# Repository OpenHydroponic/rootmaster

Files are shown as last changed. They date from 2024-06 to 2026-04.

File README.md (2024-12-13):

# RootMaster

RootMaster is an open-source hydroponics system designed to help you grow plants efficiently using a soilless solution. This project aims to provide an affordable and customizable solution for home gardeners and small-scale farmers.

## Features

- Automated nutrient delivery system
- pH and EC monitoring
- Temperature and humidity control
- Remote monitoring and control via a web interface
- Modular design for easy expansion

## Documentation

https://openhydroponics.com/hw/rootmaster

## License

This project is licensed under the CERN Open Hardware License. See the [LICENSE](LICENSE) file for details.

## Contact

For questions or support, please open an issue on the [GitLab repository](https://gitlab.com/openhydroponics/hw/rootmaster/-/issues).

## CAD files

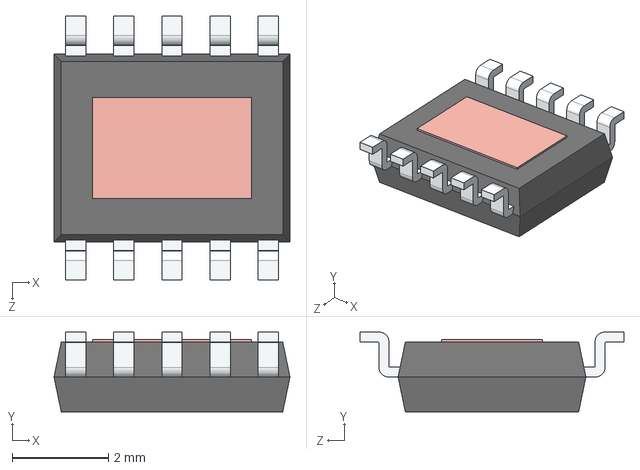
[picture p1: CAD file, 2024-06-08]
3d/ESOP-10.STEP
4.90 x 1.66 x 5.48 mm

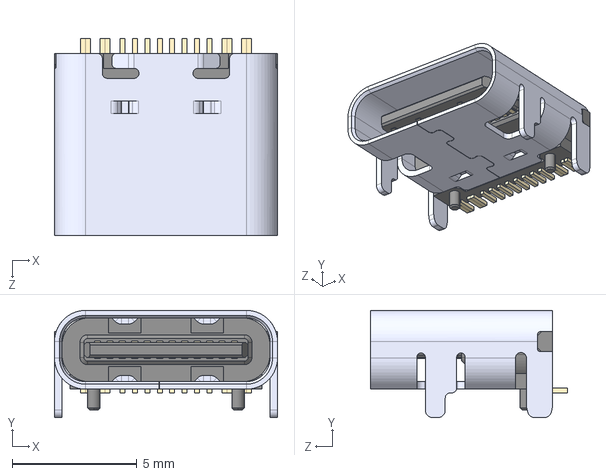
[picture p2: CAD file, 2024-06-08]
3d/TYPE-C-31-M-12--3DModel-STEP-56544.STEP
8.94 x 4.30 x 7.90 mm

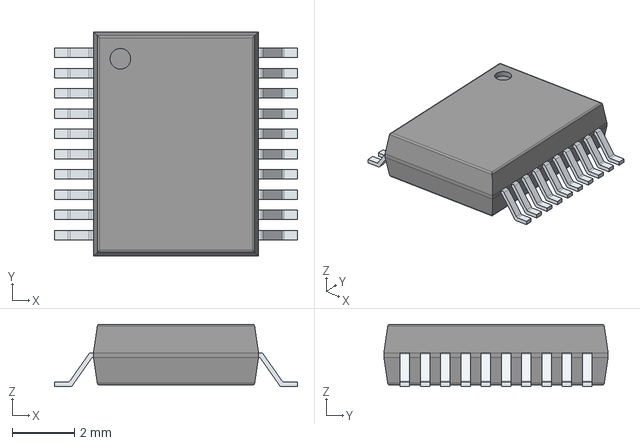
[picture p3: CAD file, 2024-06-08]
3d/ADUM6010ARSZ.stp
7.80 x 7.20 x 2.00 mm
PinsArrayLR

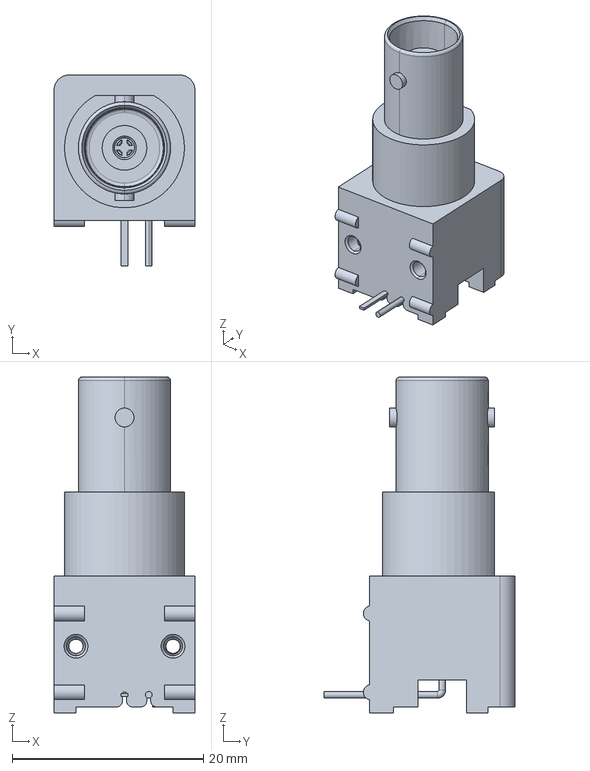
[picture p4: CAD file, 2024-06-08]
3d/c-5226990-6-b-3d.stp
14.8 x 20.0 x 35.2 mm

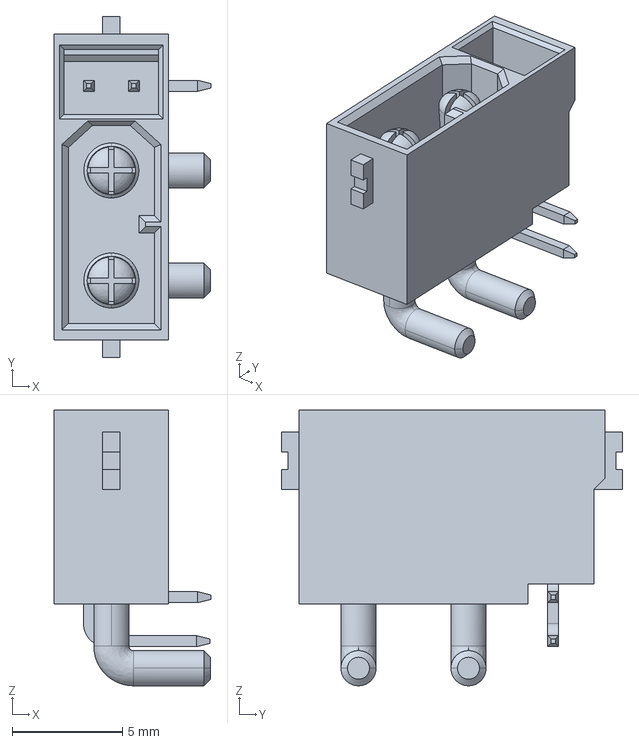
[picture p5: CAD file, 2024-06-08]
3d/XT30(2+2)PW-M 3D DRAWING.STEP.STEP
7.12 x 15.5 x 12.5 mm

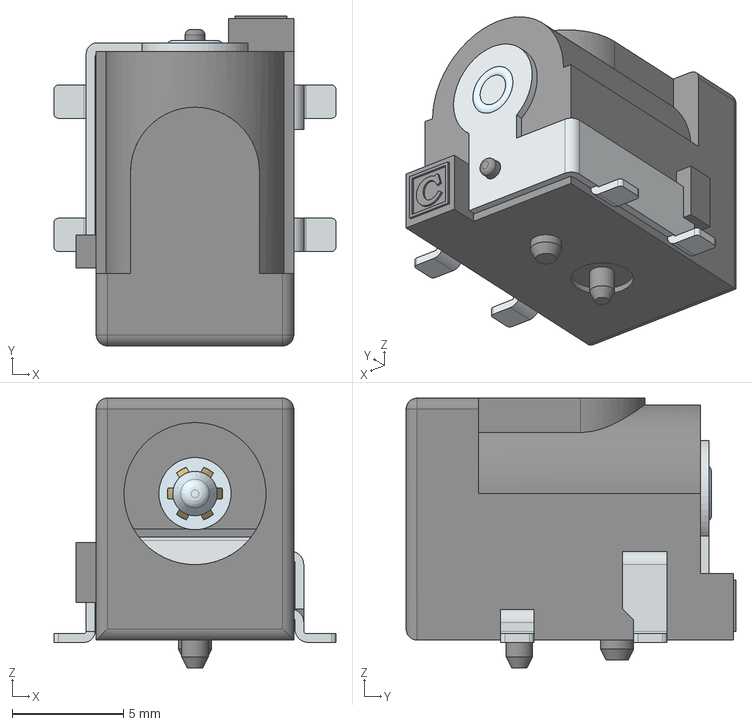
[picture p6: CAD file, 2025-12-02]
3d/FC681465S-smd.stp
12.7 x 14.8 x 12.2 mm

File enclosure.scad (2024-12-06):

include <./YAPP_Box/YAPPgenerator_v3.scad>

myPcb = "./RootMaster.stl";

//-- pcb dimensions
pcbLength           = 101; // Front to back
pcbWidth            = 101; // Side to side
pcbThickness        = 1.6;

//-- padding between pcb and inside wall
paddingFront        = 0.15;
paddingBack         = 0.15;
paddingRight        = 0.15;
paddingLeft         = 0.15;

// Base
basePlaneThickness  = 4.0;
baseWallHeight      = 10;

// Lid
lidWallHeight       = 16;
lidPlaneThickness   = 1.2;

//-- Thickness
wallThickness       = 2;


//-- ridge where base and lid off box can overlap
//-- Make sure this isn't less than lidWallHeight
ridgeHeight         = 4;
ridgeSlack          = 0.2;

//-- the radius of all outside edges and corners
roundRadius         = 2.0;

//-- How much the PCB needs to be raised from the base
//-- to leave room for solderings and whatnot
standoffHeight      = 4.0;  //-- used for PCB Supports, Push Button and showPCB
standoffDiameter    = 6;
standoffPinDiameter = 2.8;
standoffHoleSlack   = 0.3;

snapJoins =
[
    [15, 5, yappLeft, yappSymmetric, yappCenter],
    [58, 5, yappRight, yappCenter]
];

pcbStands =
[
    [4, 4, , yappDefault, yappDefault, yappDefault, yappDefault, yappDefault, 2, yappBaseOnly, yappPin, yappAllCorners],
];

cutoutsBack =
[
    [9.4, 02, 8.4, 6, 0, yappRectangle],
    [19.6, 02, 10.9, 6, 0, yappRectangle],
    [36.75, 02, 8.4, 6, 0, yappRectangle],
    [47.26, 02, 8.4, 6, 0, yappRectangle],
    [64.6, 2, 15.7, 13, 7, yappCircle], // pH
];
ridgeExtBack =
[
    [63, 17, basePlaneThickness+2+3]
];

cutoutsLeft =
[
    [56.9, 1.5, 9.2, 3.6, 0, yappRectangle], // Usb
    [43.3, 1.5, 9.4, 11.2, 0, yappRectangle], // Barreljack
];
ridgeExtLeft =
[
    [56, 11.2, 2.5]
];

cutoutsFront =
[
    [11, 1.5, 9.5, 8.3, 0, yappRectangle],   // Pump 1
    [24.7, 1.5, 9.5, 8.3, 0, yappRectangle], // Pump 2
    [38, 1.5, 9.5, 8.3, 0, yappRectangle],   // Pump 3
    [50.4, 1.5, 10.9, 6, 0, yappRectangle],// Valve 3
    [63, 1.5, 8.4, 6, 0, yappRectangle],   // Valve 2
    [73.3, 1.5, 8.4, 6, 0, yappRectangle], // Valve 1
];

cutoutsRight =
[
    [8.3, 1.5, 8.3, 5.4, 0, yappRectangle], // DigIn 1
    [16.6+1.45, 1.5, 8.3, 5.4, 0, yappRectangle],   // DigIn 2
    [26.35+1.45, 1.5, 8.3, 5.4, 0, yappRectangle],// DigIn 3
    [77.4, 1, 16.1, 6, 0, yappRectangle],   // XT30(2+2)
];

labelsPlane =
[
    [ 30, 6, 0, 0.2, yappBack, "Liberation Mono:style=bold", 3, "PH" ],
    [ 47.3, 6, 0, 0.2, yappBack, "Liberation Mono:style=bold", 3, "TEMP" ],
    [ 60, 6, 0, 0.2, yappBack, "Liberation Mono:style=bold", 3, "EC" ],
    [ 73.2, 6, 0, 0.2, yappBack, "Liberation Mono:style=bold", 3, "FLOW" ],
     [ 85, 6, 0, 0.2, yappBack, "Liberation Mono:style=bold", 3, "TEMP" ],
];

function mountLength() = pcbLength + wallThickness*2;
boxMounts =
[
    [10, 3.5, 0, 3, yappBack, yappBase],
    [mountLength()-10, 3.5, 0, 3, yappBack, yappBase],
    [10, 3.5, 0, 3, yappFront, yappBase],
    [mountLength()-10, 3.5, 0, 3, yappFront, yappBase],
];

//-- which part(s) do you want to print?
printBaseShell        = true;
printLidShell         = true;
printSwitchExtenders  = false;


// debug
//inspectX = 6;
//inspectY = 75;
showSideBySide = true;
hideBaseWalls = false;
hideLidWalls = false;
showPcb = true;

YAPPgenerate();


if (showPcb)
{
  translate([
    wallThickness+paddingBack,
    wallThickness+paddingLeft,
    basePlaneThickness+standoffHeight
  ])
  {
    rotate([0,0,0]) import(myPcb);
  }
}

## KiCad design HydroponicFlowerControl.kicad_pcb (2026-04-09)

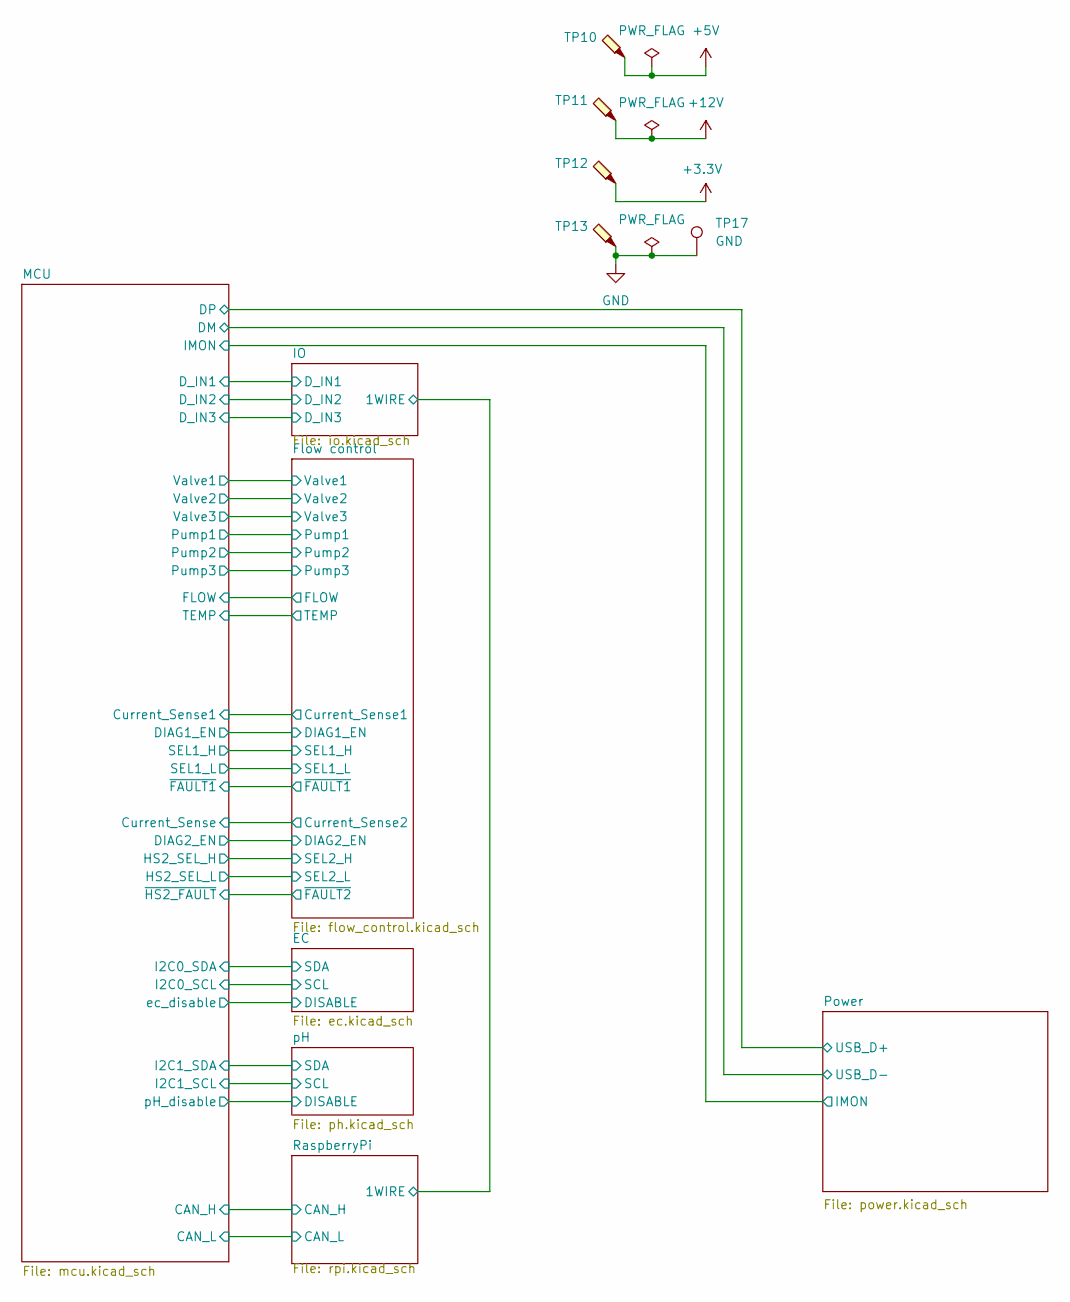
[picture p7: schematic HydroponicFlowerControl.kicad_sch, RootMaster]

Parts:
TP10: 5V; TestPoint_Pad_D1.0mm
TP11: 12V; TestPoint_Pad_D1.0mm
TP12: 3.3V; TestPoint_Pad_D1.0mm
TP13: GND; TestPoint_Loop_D1.80mm_Drill1.0mm_Beaded; LCSC C5199801
TP17: GND; TestPoint_Pad_D1.5mm

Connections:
+3.3V: TP12.1 (1_1); also elsewhere on the board
+5V: TP10.1 (1_1); also elsewhere on the board
+12V: TP11.1 (1_1); also elsewhere on the board
GND: TP13.1 (1_1), TP17.1 (1_1); also elsewhere on the board

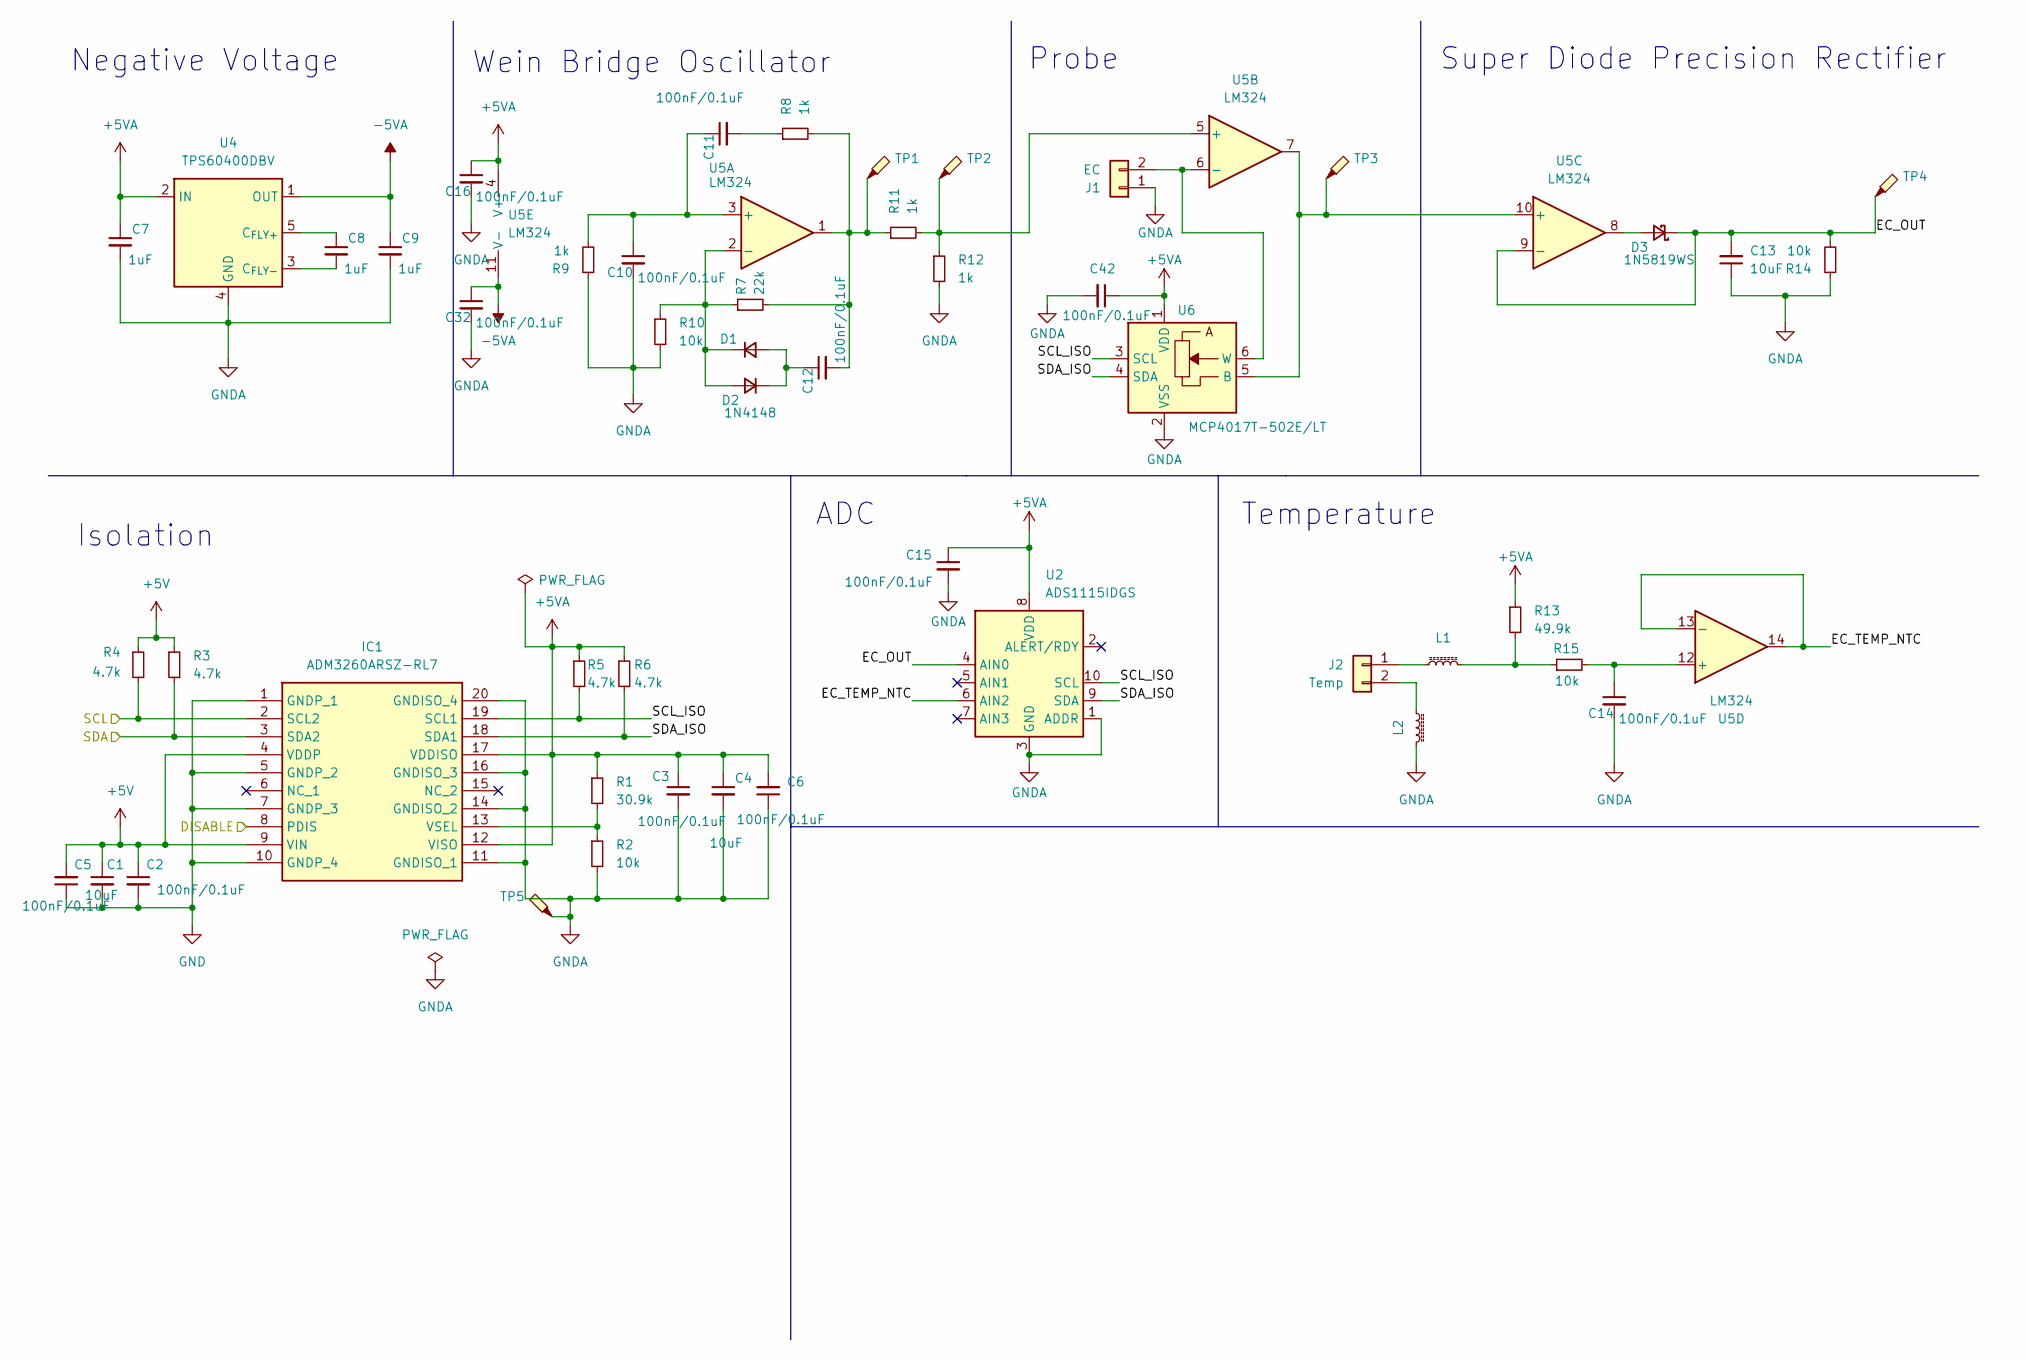
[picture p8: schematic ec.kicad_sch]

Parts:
C1, C4: 10uF; C_0603_1608Metric; LCSC C19702
C2, C3, C5, C6, C10, C11, C12, C14, C15, C16, C32, C42: 100nF/0.1uF; C_0603_1608Metric; LCSC C14663
C7, C8, C9: 1uF; C_0603_1608Metric; LCSC C15849
C13: 10uF; C_0805_2012Metric; LCSC C15850
D1, D2: 1N4148; D_SOD-323; LCSC C2128
D3: 1N5819WS; D_SOD-323; LCSC C191023
IC1: ADM3260ARSZ-RL7; SOP65P780X200-20N; Mouser Part Number 584-ADM3260ARSZ-RL7
J1: EC; JST_XH_S2B-XH-A_1x02_P2.50mm_Horizontal; LCSC C157931
J2: Temp; JST_XH_S2B-XH-A_1x02_P2.50mm_Horizontal; LCSC C157931
L1, L2: L_Ferrite_Small; L_0603_1608Metric; LCSC C1002
R1: 30.9k; R_0603_1608Metric; LCSC C23022
R2, R10, R14, R15: 10k; R_0603_1608Metric; LCSC C25804
R3, R4, R5, R6: 4.7k; R_0603_1608Metric; LCSC C23162
R7: 22k; R_0603_1608Metric; LCSC C31850
R8, R9, R11, R12: 1k; R_0603_1608Metric; LCSC C21190
R13: 49.9k; R_0603_1608Metric; LCSC C23184
TP1, TP2, TP3: TestPoint_Small; TestPoint_Pad_D1.0mm
TP4: EC; TestPoint_Pad_D1.0mm
TP5: GNDA; TestPoint_Loop_D1.80mm_Drill1.0mm_Beaded
U2: ADS1115IDGS; TSSOP-10_3x3mm_P0.5mm; LCSC C37593
U4: TPS60400DBV; SOT-23-5; LCSC C9839
U5: LM324; SOIC-14_3.9x8.7mm_P1.27mm; LCSC C71035
U6: MCP4017T-502E/LT; SOT-363_SC-70-6; LCSC C511303

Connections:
+5V: C1.1, C2.1, C5.2, IC1.4 (VDDP), IC1.9 (VIN), R3.1, R4.1; also elsewhere on the board
+5VA: C3.1, C4.1, C6.2, C7.1, C15.1, C16.1, C42.1, IC1.12 (VISO), IC1.17 (VDDISO), R1.1, R5.1, R6.1, R13.1, U2.8 (VDD), U4.2 (IN), U5.4 (V+), U6.1 (VDD)
-5VA: C9.1, C32.1, U4.1 (OUT), U5.11 (V-)
/EC/DISABLE: IC1.8 (PDIS); also elsewhere on the board
/EC/EC_OUT: C13.2, D3.1 (K), R14.2, TP4.1 (1_1), U2.4 (AIN0), U5.9 (-)
/EC/EC_TEMP_NTC: U2.6 (AIN2), U5.13 (-), U5.14
/EC/SCL: IC1.2 (SCL2), R4.2; also elsewhere on the board
/EC/SCL_ISO: IC1.19 (SCL1), R5.2, U2.10 (SCL), U6.3 (SCL)
/EC/SDA: IC1.3 (SDA2), R3.2; also elsewhere on the board
/EC/SDA_ISO: IC1.18 (SDA1), R6.2, U2.9 (SDA), U6.4 (SDA)
GND: C1.2, C2.2, C5.1, IC1.1 (GNDP_1), IC1.5 (GNDP_2), IC1.7 (GNDP_3), IC1.10 (GNDP_4); also elsewhere on the board
GNDA: C3.2, C4.2, C6.1, C7.2, C9.2, C10.2, C13.1, C14.2, C15.2, C16.2, C32.2, C42.2, IC1.11 (GNDISO_1), IC1.14 (GNDISO_2), IC1.16 (GNDISO_3), IC1.20 (GNDISO_4), J1.1, L2.2, R2.2, R9.1, R10.2, R12.2, R14.1, TP5.1 (1_1), U2.1 (ADDR), U2.3 (GND), U4.4 (GND), U6.2 (VSS)
unnamed: C11.2, R8.1
unnamed: C12.2, R7.2, R8.2, R11.1, TP1.1 (1_1), U5.1
unnamed: C12.1, D1.2 (A), D2.1 (K)
unnamed: D1.1 (K), D2.2 (A), R7.1, R10.1, U5.2 (-)
unnamed: D3.2 (A), U5.8
unnamed: IC1.13 (VSEL), R1.2, R2.1
unnamed: J1.2, U5.6 (-), U6.6 (W)
unnamed: J2.1, L1.1
unnamed: J2.2, L2.1
unnamed: L1.2, R13.2, R15.1
unnamed: C8.1, U4.5 (C_{FLY+})
unnamed: C8.2, U4.3 (C_{FLY-})
unnamed: C10.1, C11.1, R9.2, U5.3 (+)
unnamed: R11.2, R12.1, TP2.1 (1_1), U5.5 (+)
unnamed: TP3.1 (1_1), U5.7, U5.10 (+), U6.5 (B)
unnamed: C14.1, R15.2, U5.12 (+)

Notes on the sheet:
Super Diode Precision Rectifier
Probe
Negative Voltage
Temperature
Wein Bridge Oscillator
ADC
Isolation

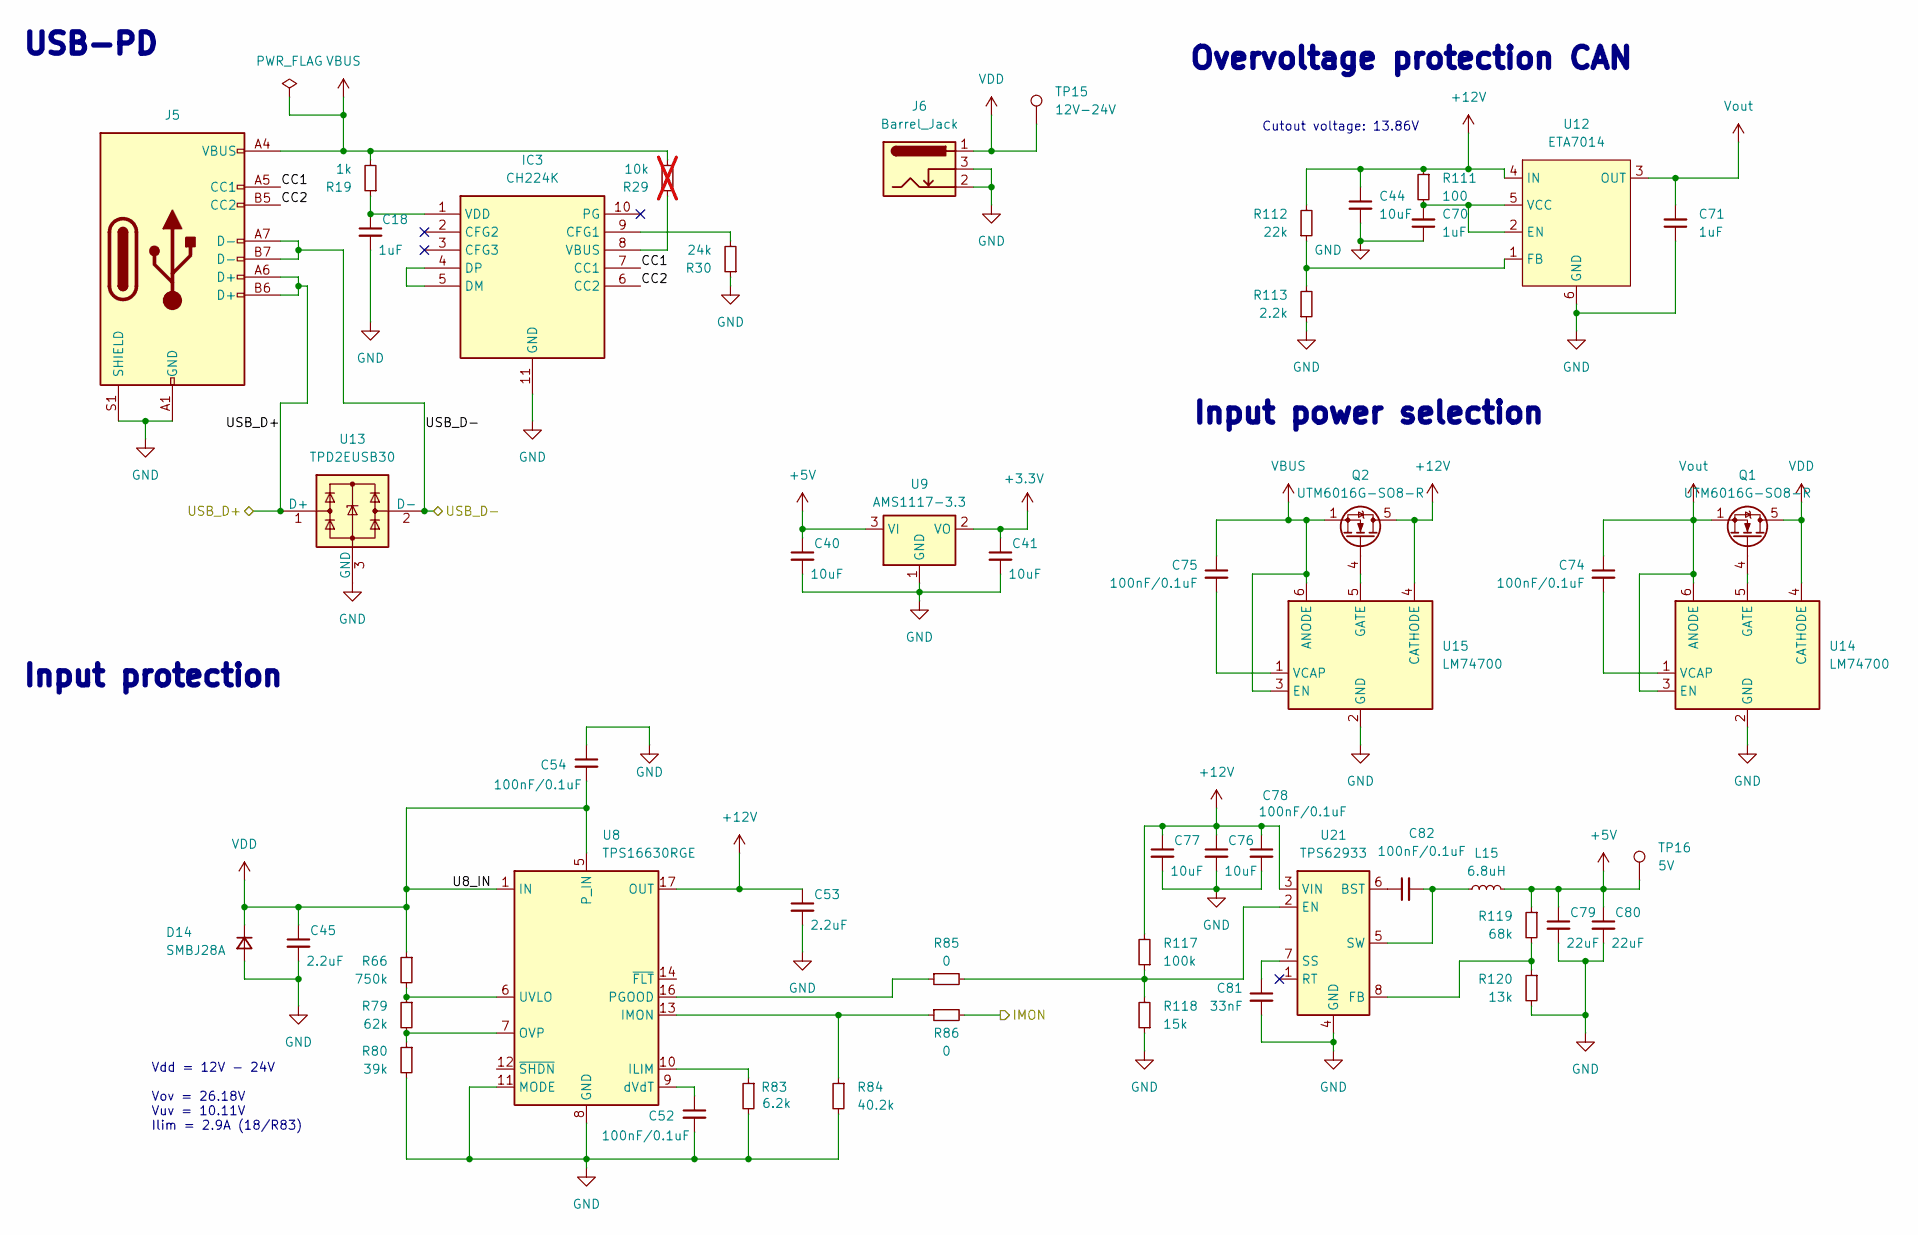
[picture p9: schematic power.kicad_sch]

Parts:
C18, C70, C71: 1uF; C_0603_1608Metric; LCSC C15849
C40, C41, C44: 10uF; C_0603_1608Metric; LCSC C19702
C45, C53: 2.2uF; C_1206_3216Metric; LCSC C50254
C52: 100nF/0.1uF; C_0402_1005Metric; LCSC C1525
C54, C78, C82: 100nF/0.1uF; C_0402_1005Metric; LCSC C307331
C74, C75: 100nF/0.1uF; C_0603_1608Metric; LCSC C14663
C76, C77: 10uF; C_1206_3216Metric; LCSC C13585
C79, C80: 22uF; C_1206_3216Metric; LCSC C12891
C81: 33nF; C_0603_1608Metric; LCSC C21117
D14: SMBJ28A; D_SMB; LCSC C19077582
IC3: CH224K; SOP100P600X180-11N; Manufacturer_Part_Number CH224K; LCSC C970725
J5: USB_C_Receptacle_USB2.0; USB_C_Receptacle_HRO_TYPE-C-31-M-12; LCSC C165948
J6: Barrel_Jack; BarrelJack_XKB_DC_005_5A_2.5_SMT_Horizontal; LCSC C319133
L15: 6.8uH; L_Sunlord_SWPA5040S; LCSC C36411
Q1, Q2: UTM6016G-SO8-R; SOIC-8_3.9x4.9mm_P1.27mm; LCSC C84901
R19: 1k; R_0603_1608Metric; LCSC C21190
R29: 10k; R_0603_1608Metric; LCSC C25804; not fitted
R30: 24k; R_0603_1608Metric; LCSC C23352
R66: 750k; R_0603_1608Metric; LCSC C23240
R79: 62k; R_0603_1608Metric; LCSC C23221
R80: 39k; R_0402_1005Metric; LCSC C25783
R83: 6.2k; R_0603_1608Metric; LCSC C4260
R84: 40.2k; R_0603_1608Metric; LCSC C12447
R85, R86: 0; R_0402_1005Metric; LCSC C17168
R111: 100; R_0402_1005Metric
R112: 22k; R_0402_1005Metric; LCSC C25768
R113: 2.2k; R_0402_1005Metric; LCSC C25879
R117: 100k; R_0603_1608Metric; LCSC C25803
R118: 15k; R_0603_1608Metric; LCSC C22809
R119: 68k; R_0603_1608Metric; LCSC C23231
R120: 13k; R_0603_1608Metric; LCSC C22797
TP15: 12V-24V; TestPoint_Pad_D1.5mm
TP16: 5V; TestPoint_Pad_D1.5mm
U8: TPS16630RGE; Texas_RGE0024H_VQFN-24-1EP_4x4mm_P0.5mm_EP2.7x2.7mm_Thermal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; LCSC C1850279
U9: AMS1117-3.3; SOT-223-3_TabPin2; LCSC C6186
U12: ETA7014; SOT-23-6; LCSC C7465500
U13: TPD2EUSB30; SOT-723; LCSC C2844720
U14, U15: LM74700; SOT-23-6; LCSC C2941042
U21: TPS62933; SOT-583-8; LCSC C3200405

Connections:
+3.3V: C41.1, U9.2 (VO); also elsewhere on the board
+5V: C40.1, C79.1, C80.1, L15.2, R119.1, TP16.1 (1_1), U9.3 (VI); also elsewhere on the board
+12V: C44.1, C53.1, C76.1, C77.1, C78.1, Q2.5 (D), Q2.6 (D), Q2.7 (D), Q2.8 (D), R111.1, R112.2, R117.2, U8.17 (OUT), U8.18 (OUT), U12.4 (IN), U15.4 (CATHODE), U21.3 (VIN); also elsewhere on the board
/MCU/IMON: R86.2; also elsewhere on the board
/Power/CC1: IC3.7 (CC1), J5.A5 (CC1)
/Power/CC2: IC3.6 (CC2), J5.B5 (CC2)
/Power/USB_D+: J5.A6 (D+), J5.B6 (D+), U13.1 (D+); also elsewhere on the board
/Power/USB_D-: J5.A7 (D-), J5.B7 (D-), U13.2 (D-); also elsewhere on the board
GND: C18.2, C40.2, C41.2, C44.2, C45.2, C52.2, C53.2, C54.1, C70.1, C71.1, C76.2, C77.2, C78.2, C79.2, C80.2, C81.2, D14.2 (A), IC3.11 (GND), J5.A1 (GND), J5.A12 (GND), J5.B1 (GND), J5.B12 (GND), J5.S1 (SHIELD), J6.2, J6.3, R30.1, R80.2, R83.2, R84.2, R113.1, R118.1, R120.2, U8.8 (GND), U8.11 (MODE), U8.25 (GND), U9.1 (GND), U12.6 (GND), U13.3 (GND), U14.2 (GND), U15.2 (GND), U21.4 (GND); also elsewhere on the board
unnamed: IC3.9 (CFG1), R30.2
unnamed: IC3.4 (DP), IC3.5 (DM)
unnamed: IC3.8 (VBUS), R29.1
unnamed: C18.1, IC3.1 (VDD), R19.1
unnamed: Q1.4 (G), U14.5 (GATE)
unnamed: Q2.4 (G), U15.5 (GATE)
unnamed: R83.1, U8.10 (ILIM)
unnamed: R84.1, R86.1, U8.13 (IMON)
unnamed: R79.2, R80.1, U8.7 (OVP)
unnamed: R85.1, U8.16 (PGOOD)
unnamed: R66.2, R79.1, U8.6 (UVLO)
unnamed: C52.1, U8.9 (dVdT)
unnamed: C70.2, R111.2, U12.2 (EN), U12.5 (VCC)
unnamed: R112.1, R113.2, U12.1 (FB)
unnamed: C74.2, U14.1 (VCAP)
unnamed: C75.2, U15.1 (VCAP)
unnamed: C82.1, U21.6 (BST)
unnamed: R85.2, R117.1, R118.2, U21.2 (EN)
unnamed: R119.2, R120.1, U21.8 (FB)
unnamed: C81.1, U21.7 (SS)
unnamed: C82.2, L15.1, U21.5 (SW)
VBUS: C75.1, J5.A4 (VBUS), J5.A9 (VBUS), J5.B4 (VBUS), J5.B9 (VBUS), Q2.1 (S), Q2.2 (S), Q2.3 (S), R19.2, R29.2, U15.3 (EN), U15.6 (ANODE)
VDD: C45.1, C54.2, D14.1 (K), J6.1, Q1.5 (D), Q1.6 (D), Q1.7 (D), Q1.8 (D), R66.1, TP15.1 (1_1), U8.1 (IN), U8.2 (IN), U8.5 (P_IN), U14.4 (CATHODE)
Vout: C71.2, C74.1, Q1.1 (S), Q1.2 (S), Q1.3 (S), U12.3 (OUT), U14.3 (EN), U14.6 (ANODE); also elsewhere on the board

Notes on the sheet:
Overvoltage protection CAN
USB-PD
Input protection
Input power selection
Vdd = 12V - 24V Vov = 26.18V Vuv = 10.11V Ilim = 2.9A (18/R83)
Cutout voltage: 13.86V

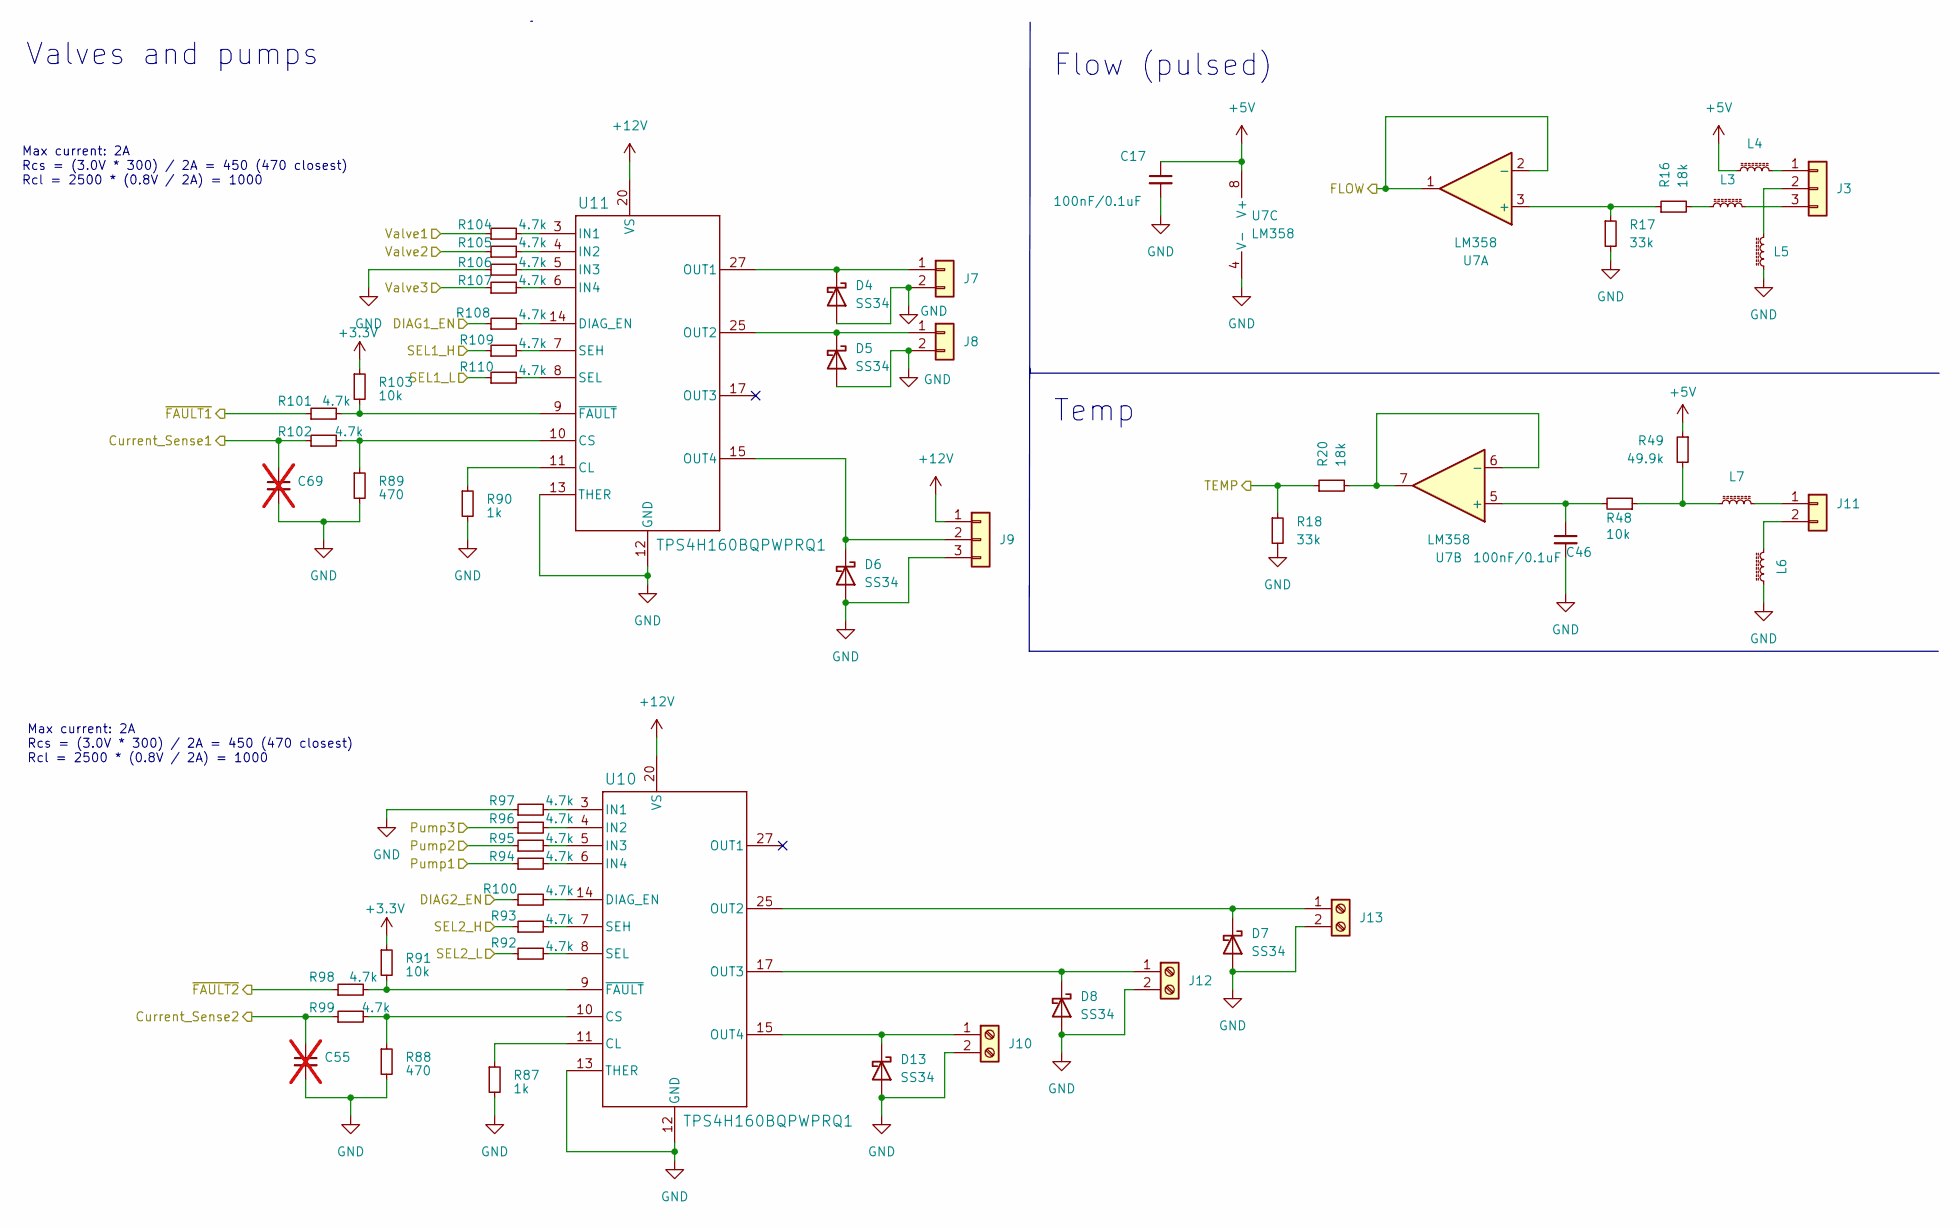
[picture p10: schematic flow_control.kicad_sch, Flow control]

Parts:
C17, C46: 100nF/0.1uF; C_0603_1608Metric; LCSC C14663
C55, C69: C_0402_1005Metric; not fitted
D4, D5, D6, D7, D8, D13: SS34; D_SMA; LCSC C8678
J3: Flow; JST_XH_S3B-XH-A_1x03_P2.50mm_Horizontal; LCSC C157928
J7: Valve 1; JST_XH_S2B-XH-A_1x02_P2.50mm_Horizontal; LCSC C157931
J8: Valve 2; JST_XH_S2B-XH-A_1x02_P2.50mm_Horizontal; LCSC C157931
J9: Valve 3; JST_XH_S3B-XH-A_1x03_P2.50mm_Horizontal; LCSC C157928
J10: Pump 1; PhoenixContact_MC_1,5_2-G-3.81_1x02_P3.81mm_Horizontal; LCSC C5188157
J11: Temperature; JST_XH_S2B-XH-A_1x02_P2.50mm_Horizontal; LCSC C157931
J12: Pump 2; PhoenixContact_MC_1,5_2-G-3.81_1x02_P3.81mm_Horizontal; LCSC C5188157
J13: Pump 3; PhoenixContact_MC_1,5_2-G-3.81_1x02_P3.81mm_Horizontal; LCSC C5188157
L3, L4, L5, L6, L7: L_Ferrite_Small; L_0603_1608Metric; LCSC C1002
R16, R20: 18k; R_0603_1608Metric; LCSC C25810
R17, R18: 33k; R_0603_1608Metric; LCSC C4216
R48: 10k; R_0603_1608Metric; LCSC C25804
R49: 49.9k; R_0603_1608Metric; LCSC C23184
R87, R90: 1k; R_0402_1005Metric; LCSC C11702
R88, R89: 470; R_0402_1005Metric; LCSC C25117
R91, R103: 10k; R_0402_1005Metric; LCSC C25744
R92, R93, R94, R95, R96, R97, R98, R99, R100, R101, R102, R104, R105, R106, R107, R108, R109, R110: 4.7k; R_0402_1005Metric; LCSC C25900
U7: LM358; SOIC-8_3.9x4.9mm_P1.27mm; LCSC C7950
U10, U11: TPS4H160BQPWPRQ1; HTSSOP-28-1EP_4.4x9.7mm_P0.65mm_EP2.85x5.4mm_ThermalVias; LCSC C471053

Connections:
+3.3V: R91.1, R103.1; also elsewhere on the board
+5V: C17.1, L4.1, R49.1, U7.8 (V+); also elsewhere on the board
+12V: J9.1, U10.20 (VS), U10.21 (VS), U10.22 (VS), U10.23 (VS), U11.20 (VS), U11.21 (VS), U11.22 (VS), U11.23 (VS); also elsewhere on the board
/Flow control/Current_Sense1: C69.1, R102.1; also elsewhere on the board
/Flow control/Current_Sense2: C55.1, R99.1; also elsewhere on the board
/Flow control/DIAG1_EN: R108.1; also elsewhere on the board
/Flow control/DIAG2_EN: R100.1; also elsewhere on the board
/Flow control/FLOW: U7.1, U7.2 (-); also elsewhere on the board
/Flow control/Pump1: R94.1; also elsewhere on the board
/Flow control/Pump2: R95.1; also elsewhere on the board
/Flow control/Pump3: R96.1; also elsewhere on the board
/Flow control/SEL1_H: R109.1; also elsewhere on the board
/Flow control/SEL1_L: R110.1; also elsewhere on the board
/Flow control/SEL2_H: R93.1; also elsewhere on the board
/Flow control/SEL2_L: R92.1; also elsewhere on the board
/Flow control/TEMP: R18.1, R20.1; also elsewhere on the board
/Flow control/Valve1: R104.1; also elsewhere on the board
/Flow control/Valve2: R105.1; also elsewhere on the board
/Flow control/Valve3: R107.1; also elsewhere on the board
/Flow control/~FAULT1: R101.1; also elsewhere on the board
/Flow control/~FAULT2: R98.1; also elsewhere on the board
GND: C17.2, C46.2, C55.2, C69.2, D4.2 (A), D5.2 (A), D6.2 (A), D7.2 (A), D8.2 (A), D13.2 (A), J7.2, J8.2, J9.3, J10.2, J12.2, J13.2, L5.1, L6.2, R17.2, R18.2, R87.2, R88.2, R89.2, R90.2, R97.1, R106.1, U7.4 (V-), U10.1 (GND), U10.12 (GND), U10.13 (THER), U10.29 (PAD), U11.1 (GND), U11.12 (GND), U11.13 (THER), U11.29 (PAD); also elsewhere on the board
unnamed: D4.1 (K), J7.1, U11.27 (OUT1), U11.28 (OUT1)
unnamed: D5.1 (K), J8.1, U11.25 (OUT2), U11.26 (OUT2)
unnamed: D6.1 (K), J9.2, U11.15 (OUT4), U11.16 (OUT4)
unnamed: D7.1 (K), J13.1, U10.25 (OUT2), U10.26 (OUT2)
unnamed: D8.1 (K), J12.1, U10.17 (OUT3), U10.18 (OUT3)
unnamed: D13.1 (K), J10.1, U10.15 (OUT4), U10.16 (OUT4)
unnamed: J3.1, L4.2
unnamed: J3.2, L5.2
unnamed: J3.3, L3.2
unnamed: J11.1, L7.1
unnamed: J11.2, L6.1
unnamed: L3.1, R16.2
unnamed: L7.2, R48.1, R49.2
unnamed: R16.1, R17.1, U7.3 (+)
unnamed: C46.1, R48.2, U7.5 (+)
unnamed: R20.2, U7.6 (-), U7.7
unnamed: R87.1, U10.11 (CL)
unnamed: R88.1, R99.2, U10.10 (CS)
unnamed: R100.2, U10.14 (DIAG_EN)
unnamed: R97.2, U10.3 (IN1)
unnamed: R96.2, U10.4 (IN2)
unnamed: R95.2, U10.5 (IN3)
unnamed: R94.2, U10.6 (IN4)
unnamed: R93.2, U10.7 (SEH)
unnamed: R92.2, U10.8 (SEL)
unnamed: R91.2, R98.2, U10.9 (~FAULT)
unnamed: R90.1, U11.11 (CL)
unnamed: R89.1, R102.2, U11.10 (CS)
unnamed: R108.2, U11.14 (DIAG_EN)
unnamed: R104.2, U11.3 (IN1)
unnamed: R105.2, U11.4 (IN2)
unnamed: R106.2, U11.5 (IN3)
unnamed: R107.2, U11.6 (IN4)
unnamed: R109.2, U11.7 (SEH)
unnamed: R110.2, U11.8 (SEL)
unnamed: R101.2, R103.2, U11.9 (~FAULT)

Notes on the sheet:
Max current: 2A Rcs = (3.0V * 300) / 2A = 450 (470 closest) Rcl = 2500 * (0.8V / 2A) = 1000
Valves and pumps
Temp
Flow (pulsed)

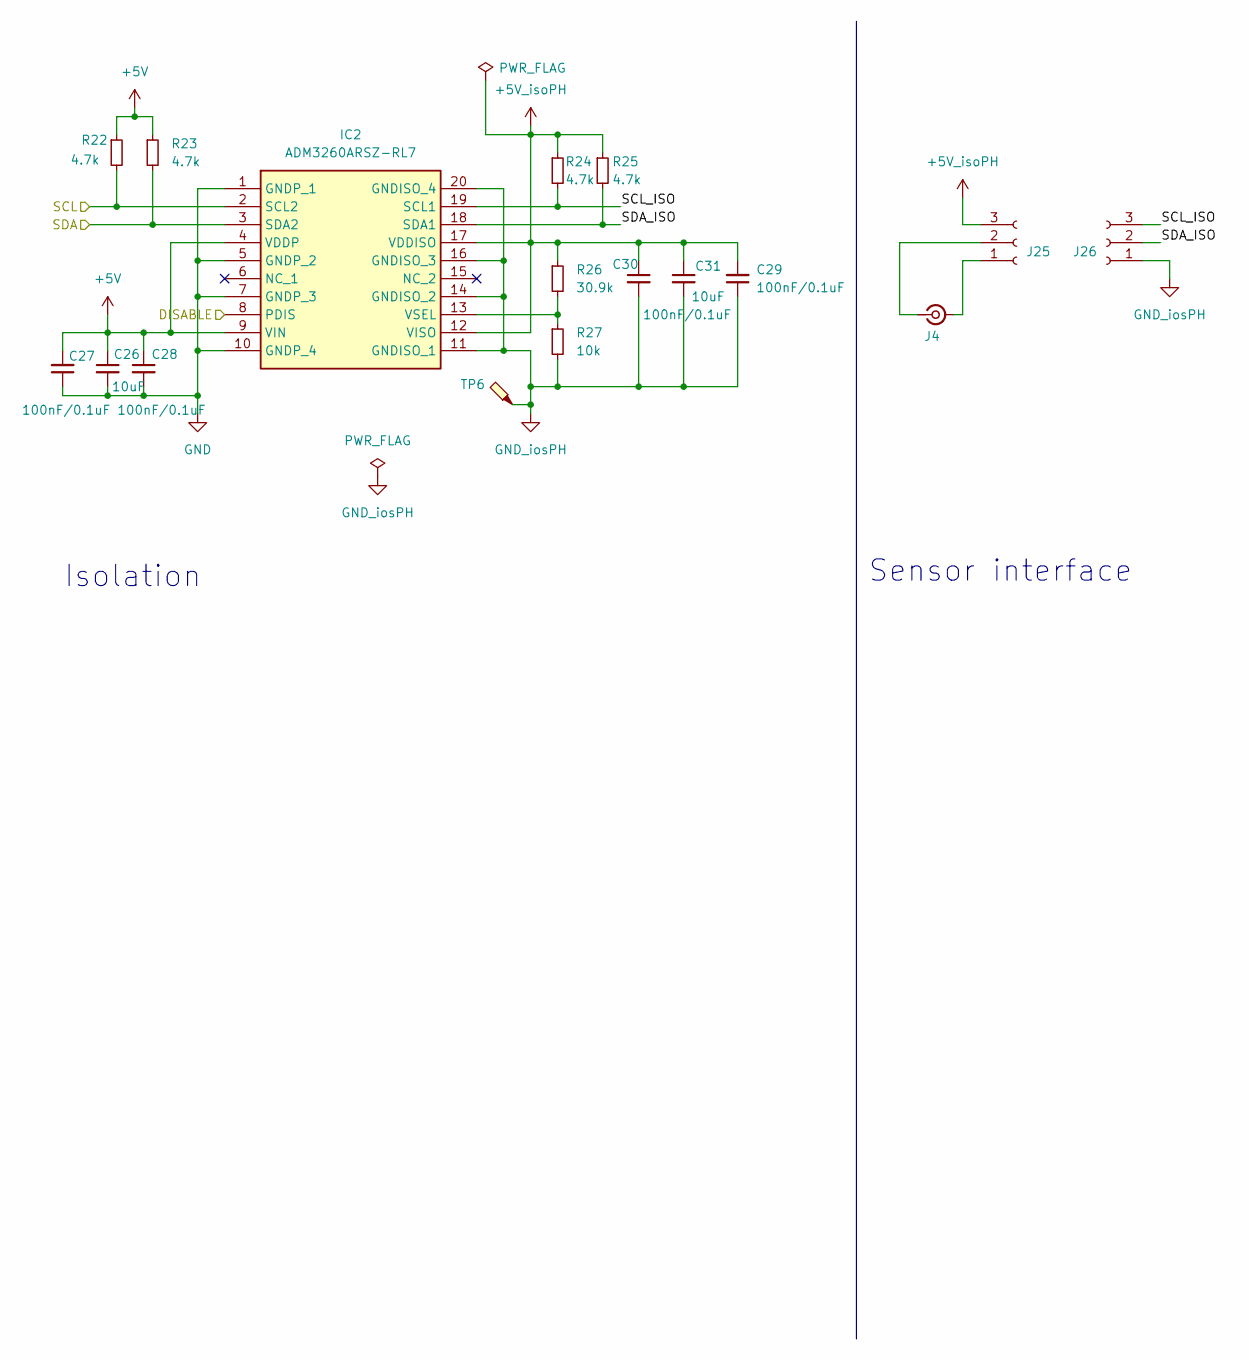
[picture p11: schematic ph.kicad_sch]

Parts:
C26, C31: 10uF; C_0603_1608Metric; LCSC C19702
C27, C28, C29, C30: 100nF/0.1uF; C_0603_1608Metric; LCSC C14663
IC2: ADM3260ARSZ-RL7; SOP65P780X200-20N; Mouser Part Number 584-ADM3260ARSZ-RL7
J4: pH; BNC_SMA; LCSC bnc C2837587
J25, J26: Conn_01x03_Socket; PinSocket_1x03_P2.54mm_Vertical_SMD_Pin1Left; LCSC C42379196
R22, R23, R24, R25: 4.7k; R_0603_1608Metric; LCSC C23162
R26: 30.9k; R_0603_1608Metric; LCSC C23022
R27: 10k; R_0603_1608Metric; LCSC C25804
TP6: GND_ISO; TestPoint_Loop_D1.80mm_Drill1.0mm_Beaded; LCSC C5199801

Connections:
+5V: C26.1, C27.2, C28.1, IC2.4 (VDDP), IC2.9 (VIN), R22.1, R23.1; also elsewhere on the board
+5V_isoPH: C29.2, C30.1, C31.1, IC2.12 (VISO), IC2.17 (VDDISO), J25.3, R24.1, R25.1, R26.1
/MCU/I2C1_SCL: IC2.2 (SCL2), R22.2; also elsewhere on the board
/MCU/I2C1_SDA: IC2.3 (SDA2), R23.2; also elsewhere on the board
/MCU/pH_disable: IC2.8 (PDIS); also elsewhere on the board
/pH/SCL_ISO: IC2.19 (SCL1), J26.3, R24.2
/pH/SDA_ISO: IC2.18 (SDA1), J26.2, R25.2
GND: C26.2, C27.1, C28.2, IC2.1 (GNDP_1), IC2.5 (GNDP_2), IC2.7 (GNDP_3), IC2.10 (GNDP_4); also elsewhere on the board
GND_iosPH: C29.1, C30.2, C31.2, IC2.11 (GNDISO_1), IC2.14 (GNDISO_2), IC2.16 (GNDISO_3), IC2.20 (GNDISO_4), J26.1, R27.2, TP6.1 (1_1)
unnamed: IC2.13 (VSEL), R26.2, R27.1
unnamed: J4.2 (Ext), J25.1
unnamed: J4.1 (In), J25.2

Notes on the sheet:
Isolation
Sensor interface

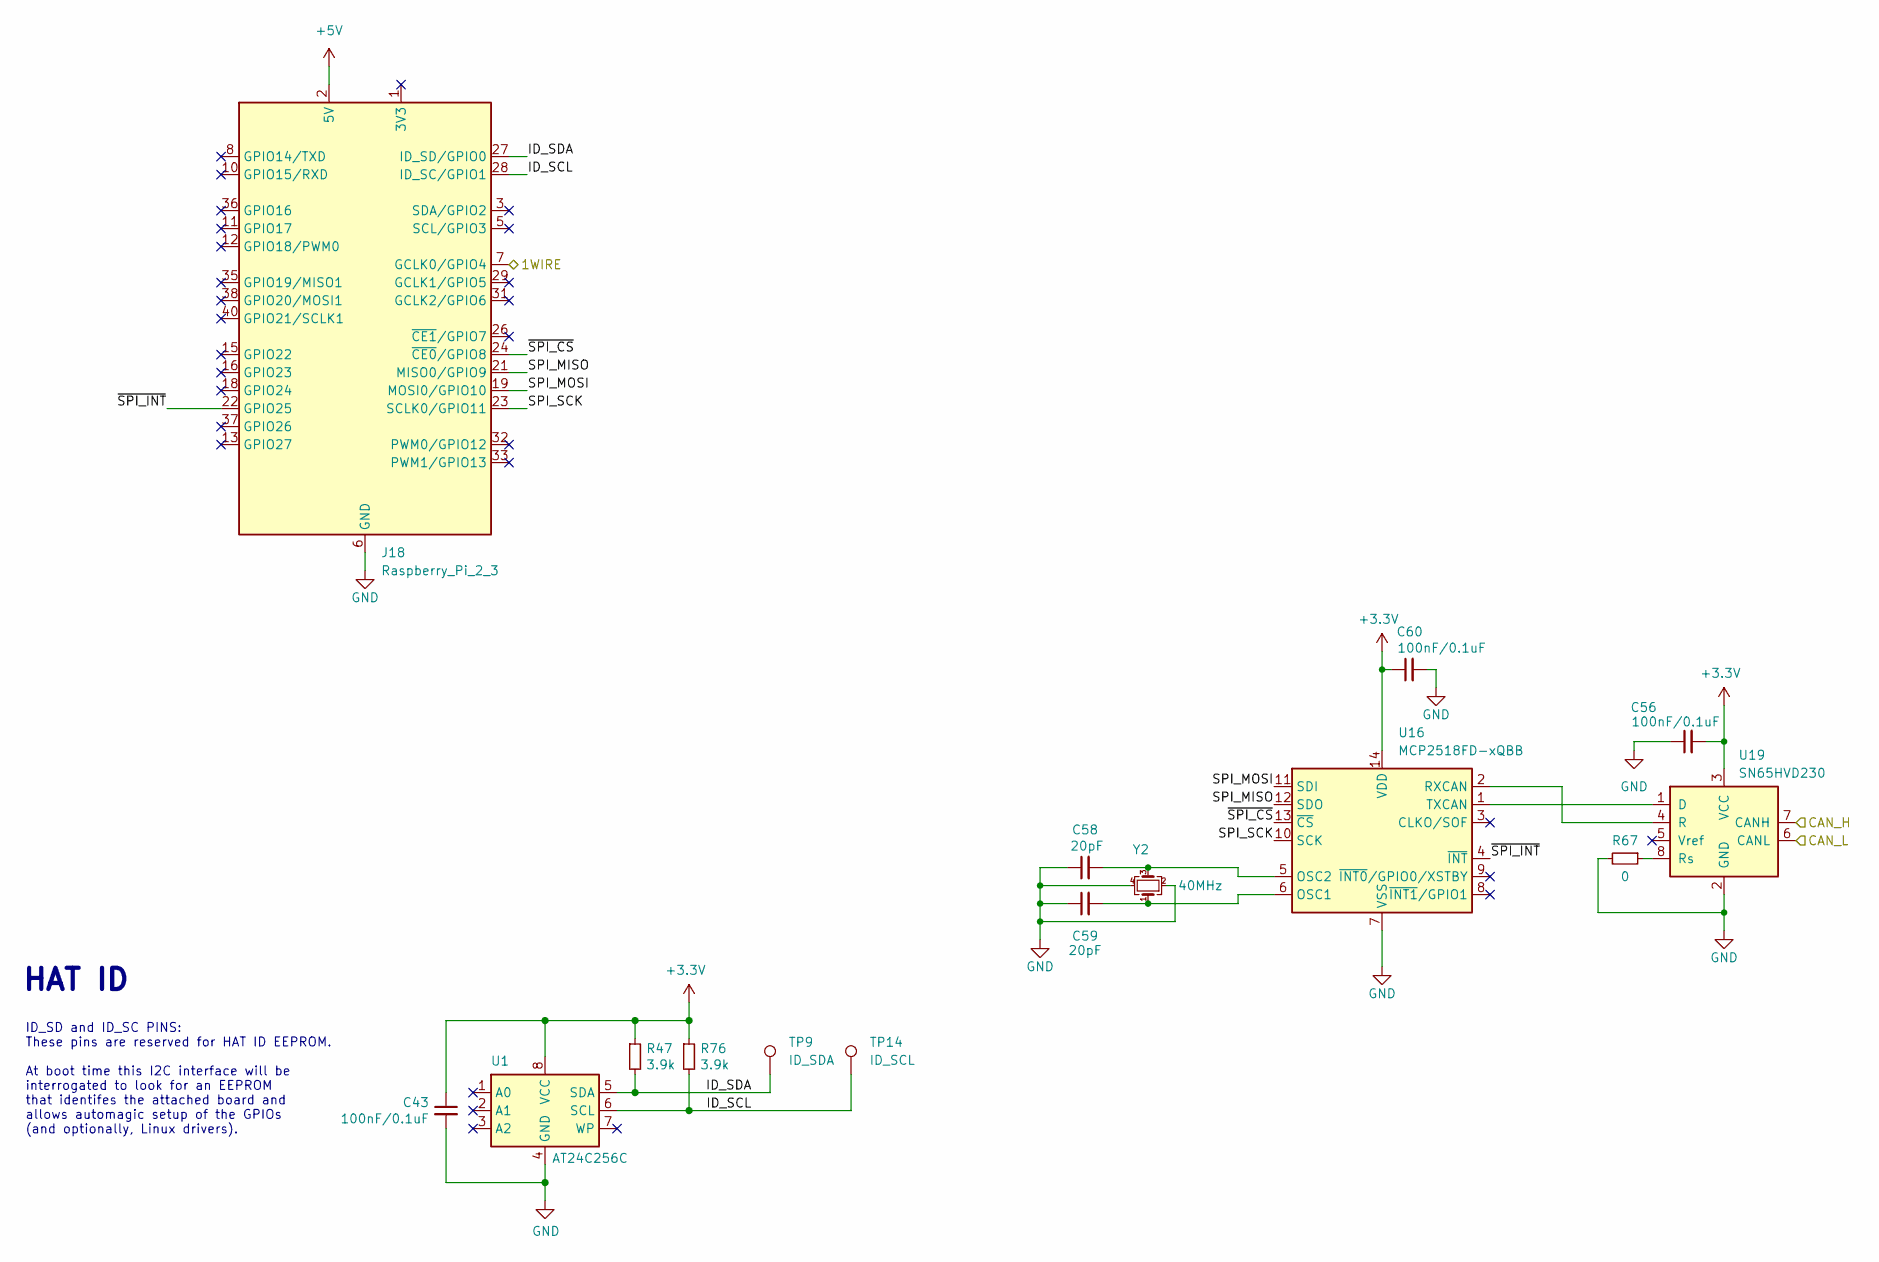
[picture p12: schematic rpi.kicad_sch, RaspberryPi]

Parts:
C43, C56, C60: 100nF/0.1uF; C_0603_1608Metric; LCSC C14663
C58, C59: 20pF; C_0603_1608Metric; LCSC C1648
J18: Raspberry_Pi_2_3; HDR-SMD_40P-P2.54-V-F-R2-C20-S7.1-EH; JLCPCB Rotation Offset 0
R47, R76: 3.9k; R_0603_1608Metric; LCSC C23018
R67: 0; R_0603_1608Metric; LCSC C21189
TP9: ID_SDA; TestPoint_Pad_D1.5mm
TP14: ID_SCL; TestPoint_Pad_D1.5mm
U1: AT24C256C; SOIC-8_3.9x4.9mm_P1.27mm; LCSC C6482
U16: MCP2518FD-xQBB; SOIC-14_3.9x8.7mm_P1.27mm; LCSC C626758
U19: SN65HVD230; SOIC-8_3.9x4.9mm_P1.27mm; LCSC C12084
Y2: 40MHz; Crystal_SMD_3225-4Pin_3.2x2.5mm; LCSC C9010

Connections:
+3.3V: C43.1, C56.2, C60.1, R47.1, R76.1, U1.8 (VCC), U16.14 (VDD), U19.3 (VCC); also elsewhere on the board
+5V: J18.2 (5V), J18.4 (5V); also elsewhere on the board
/IO/1WIRE: J18.7 (GCLK0/GPIO4); also elsewhere on the board
/MCU/CAN_H: U19.7 (CANH); also elsewhere on the board
/MCU/CAN_L: U19.6 (CANL); also elsewhere on the board
/RaspberryPi/ID_SCL: J18.28 (ID_SC/GPIO1), R76.2, TP14.1 (1_1), U1.6 (SCL)
/RaspberryPi/ID_SDA: J18.27 (ID_SD/GPIO0), R47.2, TP9.1 (1_1), U1.5 (SDA)
/RaspberryPi/SPI_MISO: J18.21 (MISO0/GPIO9), U16.12 (SDO)
/RaspberryPi/SPI_MOSI: J18.19 (MOSI0/GPIO10), U16.11 (SDI)
/RaspberryPi/SPI_SCK: J18.23 (SCLK0/GPIO11), U16.10 (SCK)
/RaspberryPi/~SPI_CS: J18.24 (~CE0/GPIO8), U16.13 (~CS)
/RaspberryPi/~SPI_INT: J18.22 (GPIO25), U16.4 (~INT)
GND: C43.2, C56.1, C58.1, C59.1, C60.2, J18.6 (GND), J18.9 (GND), J18.14 (GND), J18.20 (GND), J18.25 (GND), J18.30 (GND), J18.34 (GND), J18.39 (GND), R67.2, U1.4 (GND), U16.7 (VSS), U16.15 (VSS), U19.2 (GND), Y2.2, Y2.4; also elsewhere on the board
unnamed: C59.2, U16.6 (OSC1), Y2.1
unnamed: C58.2, U16.5 (OSC2), Y2.3
unnamed: U16.2 (RXCAN), U19.4 (R)
unnamed: U16.1 (TXCAN), U19.1 (D)
unnamed: R67.1, U19.8 (Rs)

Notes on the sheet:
ID_SD and ID_SC PINS: These pins are reserved for HAT ID EEPROM. At boot time this I2C interface will be interrogated to look for an EEPROM that identifes the attached board and allows automagic setup of the GPIOs (and optionally, Linux drivers).
HAT ID

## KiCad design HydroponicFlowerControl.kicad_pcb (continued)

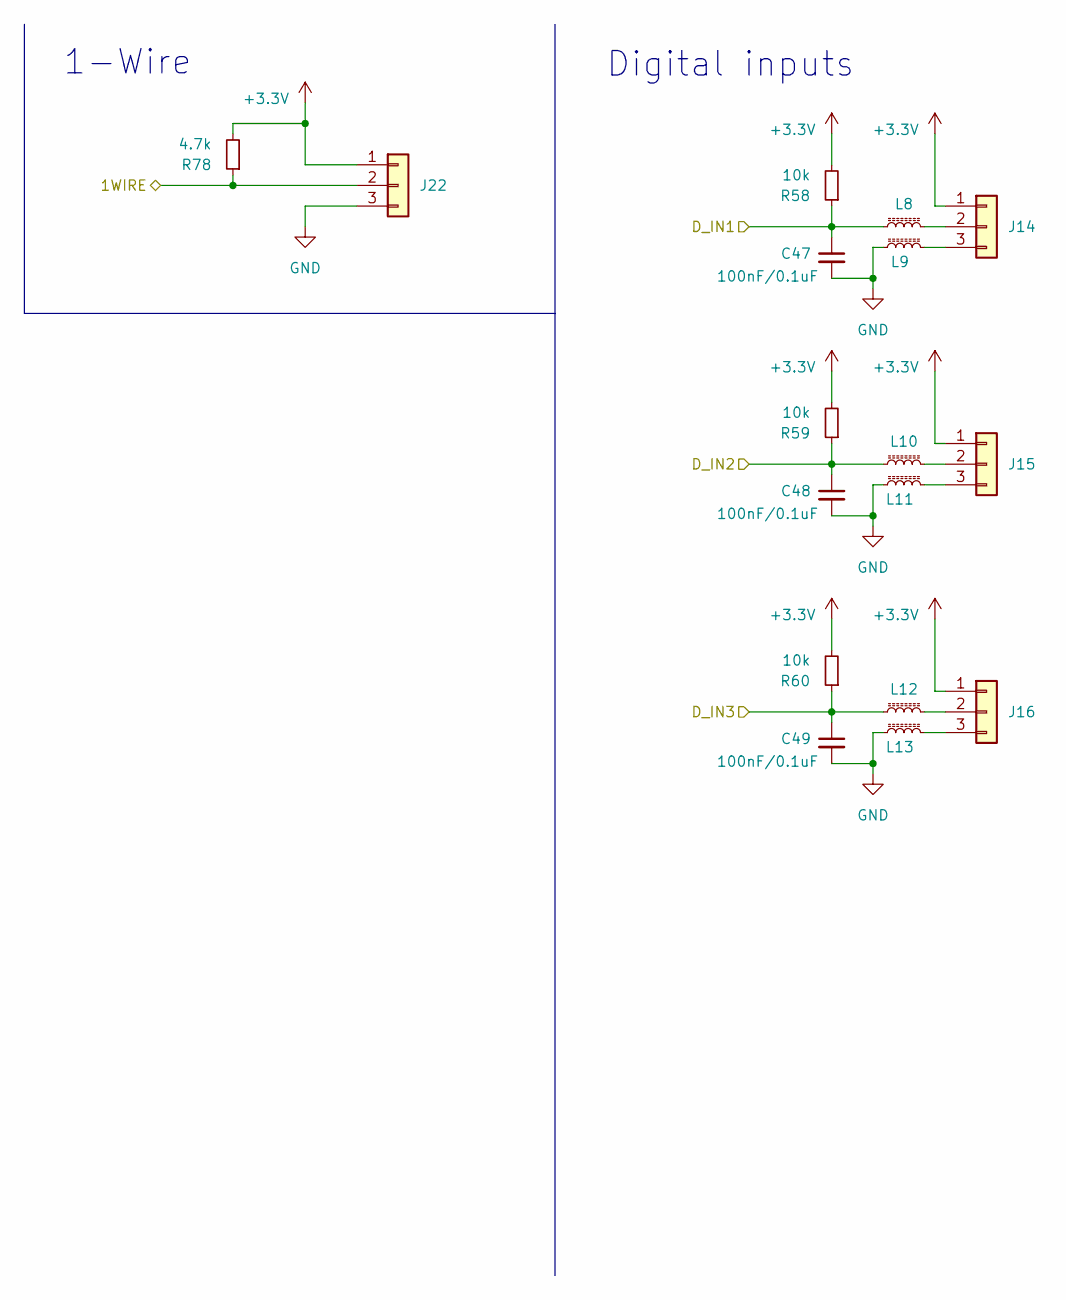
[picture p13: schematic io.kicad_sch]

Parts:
C47, C48, C49: 100nF/0.1uF; C_0603_1608Metric; LCSC C14663
J14: D IN1; JST_PH_S3B-PH-K_1x03_P2.00mm_Horizontal; LCSC C157929
J15: D IN2; JST_PH_S3B-PH-K_1x03_P2.00mm_Horizontal; LCSC C157929
J16: D IN3; JST_PH_S3B-PH-K_1x03_P2.00mm_Horizontal; LCSC C157929
J22: 1-Wire; PinHeader_1x03_P2.54mm_Vertical
L8, L9, L10, L11, L12, L13: L_Ferrite_Small; L_0603_1608Metric; LCSC C1002
R58, R59, R60: 10k; R_0603_1608Metric; LCSC C25804
R78: 4.7k; R_0603_1608Metric; LCSC C23162

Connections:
+3.3V: J14.1, J15.1, J16.1, J22.1, R58.2, R59.2, R60.2, R78.2; also elsewhere on the board
/IO/1WIRE: J22.2, R78.1; also elsewhere on the board
/IO/D_IN1: C47.1, L8.2, R58.1; also elsewhere on the board
/IO/D_IN2: C48.1, L10.2, R59.1; also elsewhere on the board
/IO/D_IN3: C49.1, L12.2, R60.1; also elsewhere on the board
GND: C47.2, C48.2, C49.2, J22.3, L9.2, L11.2, L13.2; also elsewhere on the board
unnamed: J14.2, L8.1
unnamed: J14.3, L9.1
unnamed: J15.2, L10.1
unnamed: J15.3, L11.1
unnamed: J16.2, L12.1
unnamed: J16.3, L13.1

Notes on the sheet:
Digital inputs
1-Wire

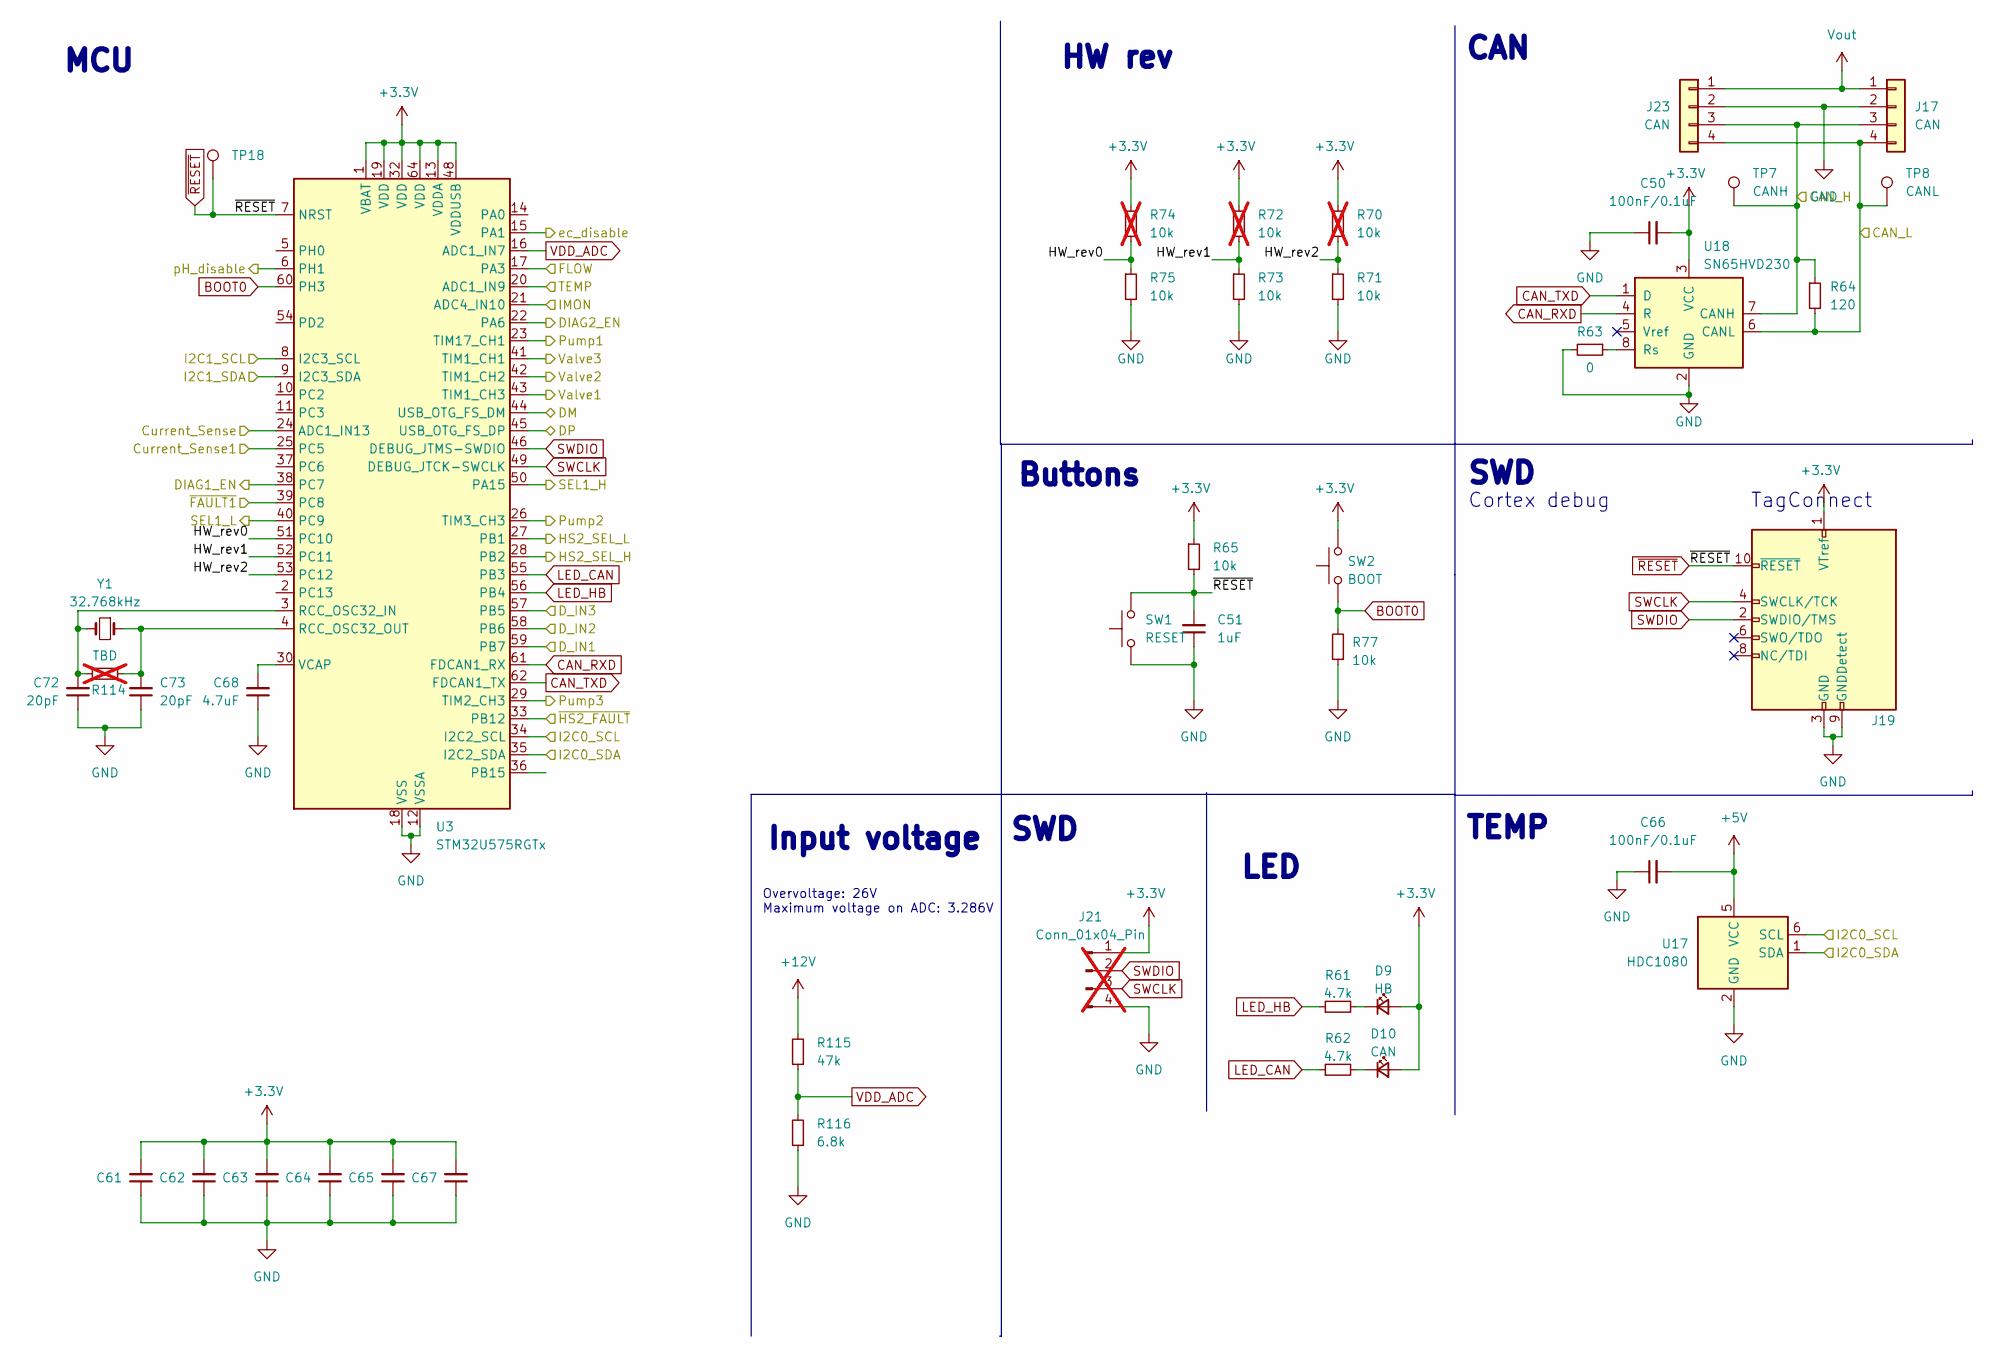
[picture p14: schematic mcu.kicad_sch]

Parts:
C50, C66: 100nF/0.1uF; C_0603_1608Metric; LCSC C14663
C51: 1uF; C_0603_1608Metric; LCSC C15849
C61, C62, C63, C64, C65, C67: 100nF/0.1uF; C_0402_1005Metric; LCSC C1525
C68: 4.7uF; C_0402_1005Metric; LCSC C23733
C72, C73: 20pF; C_0402_1005Metric; LCSC C1554
D9: HB; LED_0603_1608Metric; LCSC C72038
D10: CAN; LED_0603_1608Metric; LCSC C72038
J17, J23: CAN; AMASS_XT30PW(2+2); LCSC C19268030
J19: Conn_ARM_JTAG_SWD_10; Tag-Connect_TC2050-IDC-FP_2x05_P1.27mm_Vertical
J21: Conn_01x04_Pin; PinHeader_1x04_P2.54mm_Vertical; LCSC C6332197; not fitted
R61, R62: 4.7k; R_0603_1608Metric; LCSC C23162
R63: 0; R_0603_1608Metric; LCSC C21189
R64: 120; R_1206_3216Metric; LCSC C17909
R65, R77: 10k; R_0603_1608Metric; LCSC C25804
R70, R72, R74: 10k; R_0402_1005Metric; LCSC C25744; not fitted
R71, R73, R75: 10k; R_0402_1005Metric; LCSC C25744
R114: TBD; R_0402_1005Metric; not fitted
R115: 47k; R_0603_1608Metric; LCSC C25819
R116: 6.8k; R_0603_1608Metric; LCSC C23212
SW1: RESET; SW_SPST_TL3342; LCSC C318884
SW2: BOOT; SW_SPST_TL3342; LCSC C318884
TP7: CANH; TestPoint_Pad_D1.5mm
TP8: CANL; TestPoint_Pad_D1.5mm
TP18: Reset; TestPoint_Pad_D1.5mm
U3: STM32U575RGTx; LQFP-64_10x10mm_P0.5mm; LCSC C5270980
U17: HDC1080; Texas_PWSON-N6; LCSC C82227
U18: SN65HVD230; SOIC-8_3.9x4.9mm_P1.27mm; LCSC C12084
Y1: 32.768kHz; Crystal_SMD_3215-2Pin_3.2x1.5mm; LCSC C32346

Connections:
+3.3V: C50.2, C61.2, C62.2, C63.2, C64.2, C65.2, C67.2, D9.2 (A), D10.2 (A), J19.1 (VTref), J21.1, R65.1, R70.1, R72.1, R74.1, SW2.2, U3.1 (VBAT), U3.13 (VDDA), U3.19 (VDD), U3.32 (VDD), U3.48 (VDDUSB), U3.64 (VDD), U18.3 (VCC); also elsewhere on the board
+5V: C66.2, U17.5 (VCC); also elsewhere on the board
+12V: R115.2; also elsewhere on the board
/EC/DISABLE: U3.15 (PA1); also elsewhere on the board
/EC/SCL: U3.34 (I2C2_SCL), U17.6 (SCL); also elsewhere on the board
/EC/SDA: U3.35 (I2C2_SDA), U17.1 (SDA); also elsewhere on the board
/Flow control/Current_Sense1: U3.25 (PC5); also elsewhere on the board
/Flow control/Current_Sense2: U3.24 (ADC1_IN13); also elsewhere on the board
/Flow control/DIAG1_EN: U3.38 (PC7); also elsewhere on the board
/Flow control/DIAG2_EN: U3.22 (PA6); also elsewhere on the board
/Flow control/FLOW: U3.17 (PA3); also elsewhere on the board
/Flow control/Pump1: U3.23 (TIM17_CH1); also elsewhere on the board
/Flow control/Pump2: U3.26 (TIM3_CH3); also elsewhere on the board
/Flow control/Pump3: U3.29 (TIM2_CH3); also elsewhere on the board
/Flow control/SEL1_H: U3.50 (PA15); also elsewhere on the board
/Flow control/SEL1_L: U3.40 (PC9); also elsewhere on the board
/Flow control/SEL2_H: U3.28 (PB2); also elsewhere on the board
/Flow control/SEL2_L: U3.27 (PB1); also elsewhere on the board
/Flow control/TEMP: U3.20 (ADC1_IN9); also elsewhere on the board
/Flow control/Valve1: U3.43 (TIM1_CH3); also elsewhere on the board
/Flow control/Valve2: U3.42 (TIM1_CH2); also elsewhere on the board
/Flow control/Valve3: U3.41 (TIM1_CH1); also elsewhere on the board
/Flow control/~FAULT1: U3.39 (PC8); also elsewhere on the board
/Flow control/~FAULT2: U3.33 (PB12); also elsewhere on the board
/IO/D_IN1: U3.59 (PB7); also elsewhere on the board
/IO/D_IN2: U3.58 (PB6); also elsewhere on the board
/IO/D_IN3: U3.57 (PB5); also elsewhere on the board
/MCU/CAN_H: J17.3, J23.3, R64.1, TP7.1 (1_1), U18.7 (CANH); also elsewhere on the board
/MCU/CAN_L: J17.4, J23.4, R64.2, TP8.1 (1_1), U18.6 (CANL); also elsewhere on the board
/MCU/HW_rev0: R74.2, R75.1, U3.51 (PC10)
/MCU/HW_rev1: R72.2, R73.1, U3.52 (PC11)
/MCU/HW_rev2: R70.2, R71.1, U3.53 (PC12)
/MCU/I2C1_SCL: U3.8 (I2C3_SCL); also elsewhere on the board
/MCU/I2C1_SDA: U3.9 (I2C3_SDA); also elsewhere on the board
/MCU/IMON: U3.21 (ADC4_IN10); also elsewhere on the board
/MCU/pH_disable: U3.6 (PH1); also elsewhere on the board
/Power/USB_D+: U3.45 (USB_OTG_FS_DP); also elsewhere on the board
/Power/USB_D-: U3.44 (USB_OTG_FS_DM); also elsewhere on the board
BOOT0: R77.2, SW2.1, U3.60 (PH3)
CAN_RXD: U3.61 (FDCAN1_RX), U18.4 (R)
CAN_TXD: U3.62 (FDCAN1_TX), U18.1 (D)
GND: C50.1, C51.1, C61.1, C62.1, C63.1, C64.1, C65.1, C66.1, C67.1, C68.1, C72.1, C73.1, J17.2, J19.3 (GND), J19.5 (GND), J19.9 (GNDDetect), J21.4, J23.2, R63.2, R71.2, R73.2, R75.2, R77.1, R116.1, SW1.1, U3.12 (VSSA), U3.18 (VSS), U3.31 (VSS), U3.47 (VSS), U3.63 (VSS), U17.2 (GND), U18.2 (GND); also elsewhere on the board
LED_CAN: R62.1, U3.55 (PB3)
LED_HB: R61.1, U3.56 (PB4)
unnamed: D9.1 (K), R61.2
unnamed: D10.1 (K), R62.2
unnamed: C72.2, R114.1, U3.3 (RCC_OSC32_IN), Y1.2
unnamed: C73.2, R114.2, U3.4 (RCC_OSC32_OUT), Y1.1
unnamed: C68.2, U3.30 (VCAP)
unnamed: R63.1, U18.8 (Rs)
SWCLK: J19.4 (SWCLK/TCK), J21.3, U3.49 (DEBUG_JTCK-SWCLK)
SWDIO: J19.2 (SWDIO/TMS), J21.2, U3.46 (DEBUG_JTMS-SWDIO)
VDD_ADC: R115.1, R116.2, U3.16 (ADC1_IN7)
Vout: J17.1, J23.1; also elsewhere on the board
~RESET: C51.2, J19.10 (~RESET), R65.2, SW1.2, TP18.1 (1_1), U3.7 (NRST)

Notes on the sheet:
TEMP
Buttons
SWD
HW rev
LED
Overvoltage: 26V Maximum voltage on ADC: 3.286V
TagConnect
MCU
CAN
Cortex debug
Input voltage

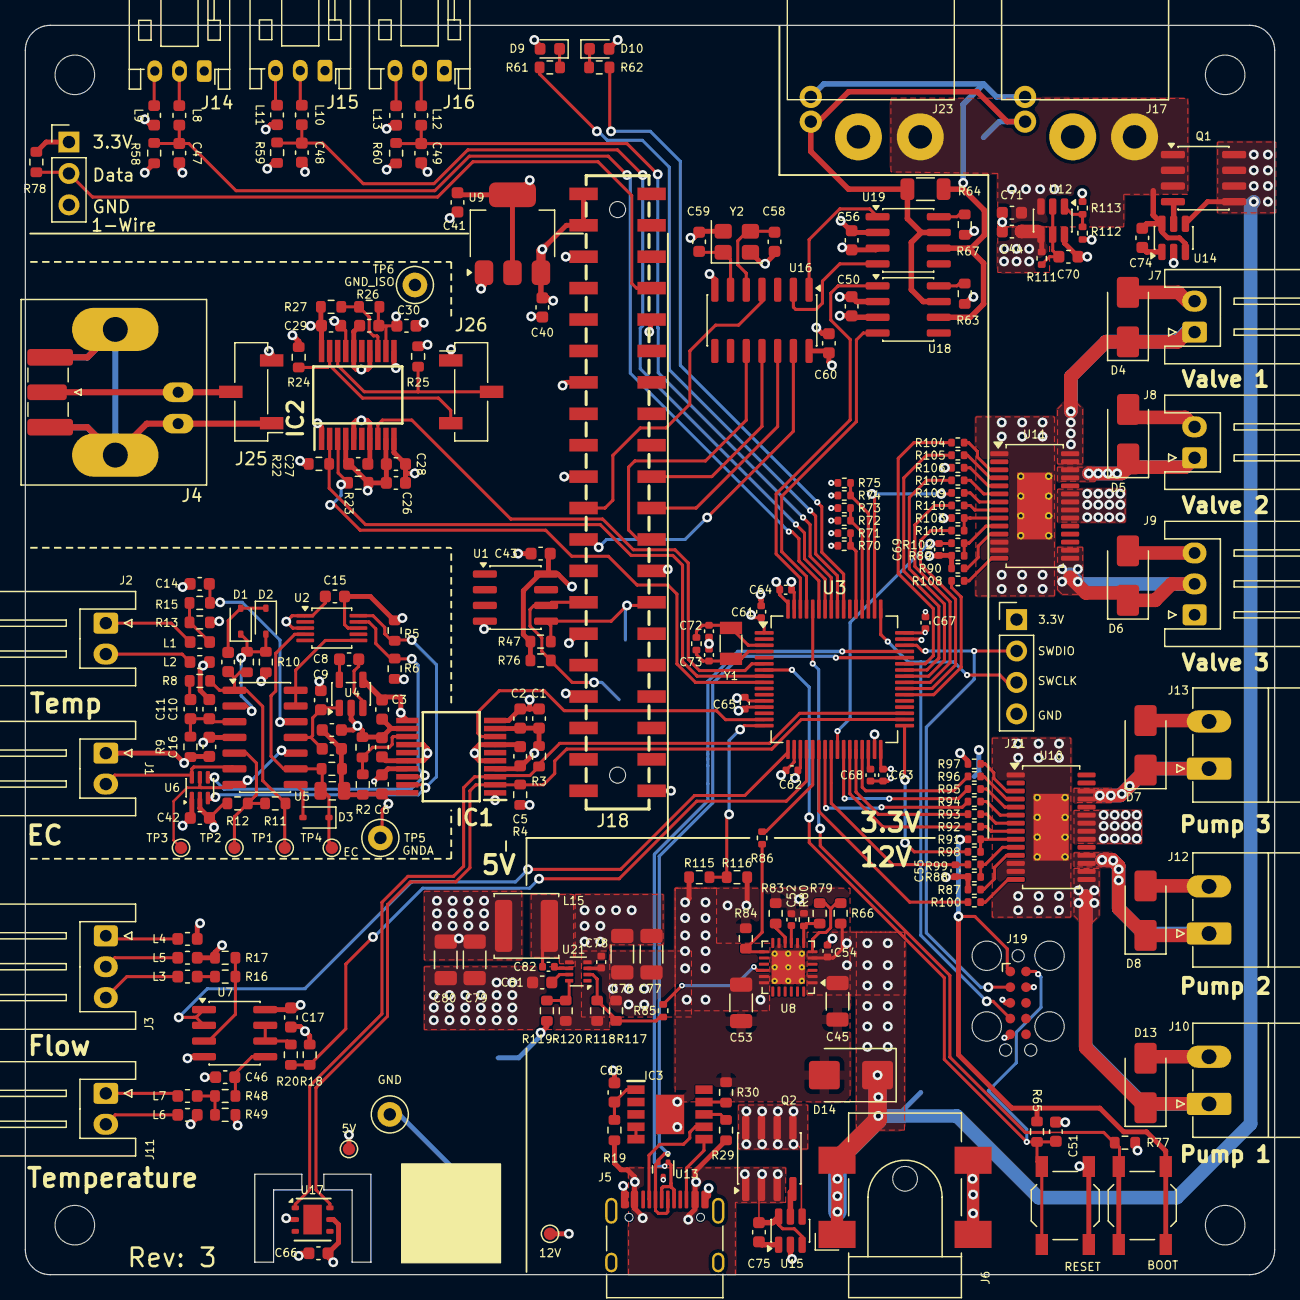
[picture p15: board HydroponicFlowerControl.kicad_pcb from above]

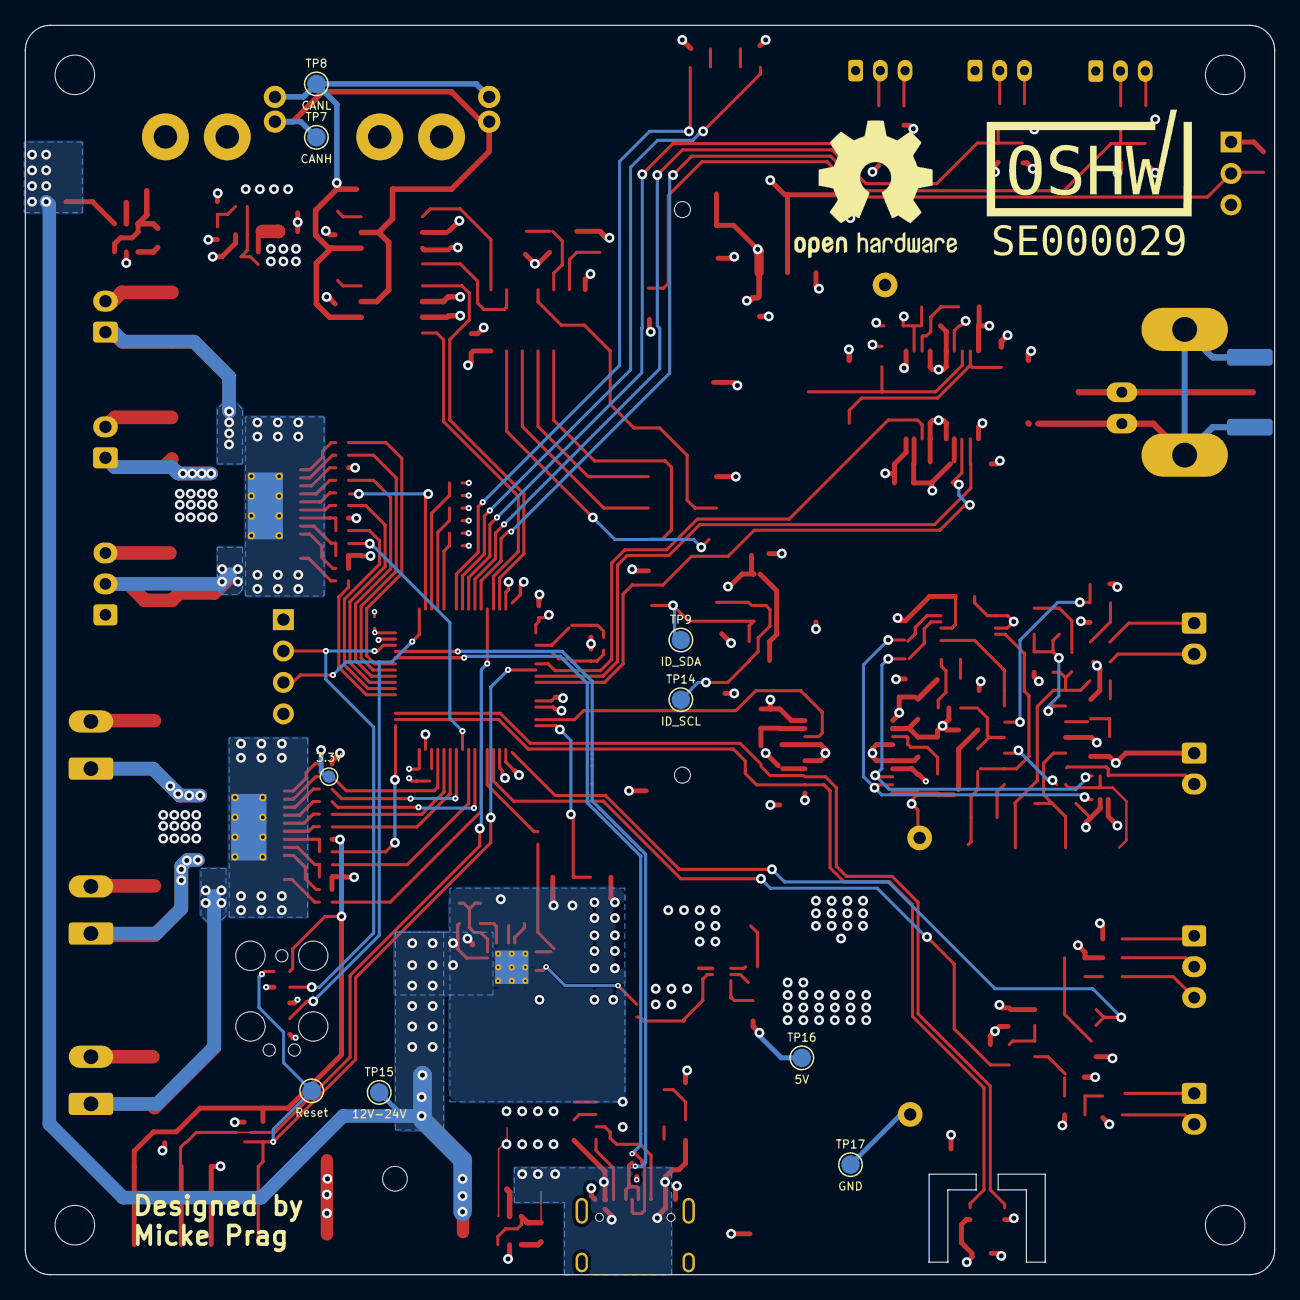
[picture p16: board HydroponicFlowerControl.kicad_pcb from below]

Board: 4 copper layers, 101.0 x 101.0 mm, 254 parts (9 on the bottom side), 165 nets.

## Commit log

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2024-06-08 Add title to all schematics pages
    [HydroponicFlowerControl.kicad_sch, ec.kicad_sch, flow_control.kicad_sch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]
2024-06-10 Redesign board to fit within 102mm x 102mm
    [HydroponicFlowerControl.kicad_pcb, ec.kicad_sch, flow_control.kicad_sch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]
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2024-10-27 Switch isolators to ADM3260
    Change EC isolator.
    See #1
    [HydroponicFlowerControl.kicad_pcb, ec.kicad_sch]
2024-10-27 Switch isolators to ADM3260
    Change pH isolator
    Closes #1
    [HydroponicFlowerControl.kicad_pcb, ph.kicad_sch]
2024-10-27 Add disable signals for ec and ph
    [HydroponicFlowerControl.kicad_pcb, HydroponicFlowerControl.kicad_sch, ec.kicad_sch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]
2024-10-27 Decrease size of raspberry pi mounting holes
    [HydroponicFlowerControl.kicad_pcb, rpi.kicad_sch]
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2024-10-27 Add keepout zone for copper fills around temp sensor
    [HydroponicFlowerControl.kicad_pcb]
2024-10-27 Update max current for motor controller
    Closes #8
    [HydroponicFlowerControl.kicad_pcb, flow_control.kicad_sch]
2024-10-27 Swap source and drain on mosfets
    Closes #4
    [HydroponicFlowerControl.kicad_pcb, flow_control.kicad_sch]
2024-10-28 Replace motor controller with mosfets instead
    Closes #21
    [HydroponicFlowerControl.kicad_pcb, HydroponicFlowerControl.kicad_sch, flow_control.kicad_sch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]
2024-10-28 Replace RPi connector
    New variant is SMD type and has been rotated.
    Closes #16 and #11
    [HydroponicFlowerControl.kicad_pcb, rpi.kicad_sch]
2024-10-28 Add Cortex debug connector
    Closes #17
    [HydroponicFlowerControl.kicad_pcb, mcu.kicad_sch]
2024-10-29 Tie boot0 (PB8) to GND
    Closes #2
    [HydroponicFlowerControl.kicad_pcb, mcu.kicad_sch]
2024-10-29 Add RPi ID EEPROM
    Closes #15
    [HydroponicFlowerControl.kicad_pcb, rpi.kicad_sch]
2024-10-29 Switch to basic components for 5V LDO feedback
    [HydroponicFlowerControl.kicad_pcb, power.kicad_sch]
2024-11-03 Fix manufaturing properties
    Such as rotations
    [HydroponicFlowerControl.kicad_pcb, ec.kicad_sch, mcu.kicad_sch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]
2024-11-03 Move R15 and R48 to the right side of the divider
    Closes #6
    [HydroponicFlowerControl.kicad_pcb, ec.kicad_sch, flow_control.kicad_sch]
2024-11-03 Optimize EC RC filter
    Closes #5
    [HydroponicFlowerControl.kicad_pcb, ec.kicad_sch]
2024-11-03 Protect PH_OUT from going out of bounds
    Closes #7
    [HydroponicFlowerControl.kicad_pcb, ph.kicad_sch]
2024-11-08 Add testpoints for power and gnd
    Closes #3
    [HydroponicFlowerControl.kicad_pcb, HydroponicFlowerControl.kicad_sch, ec.kicad_sch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]
2024-11-08 Replace C57
    With a variant that can be used with economy pcbs at JLCPCB
    Closes #25
    [HydroponicFlowerControl.kicad_pcb, power.kicad_sch]
2024-11-08 Replace DC connector with SMD variant
    Closes #23
    [HydroponicFlowerControl.kicad_pcb, power.kicad_sch]
2024-11-08 Replace the mcu to a STM32G473 variant
    [HydroponicFlowerControl.kicad_pcb, mcu.kicad_sch]
2024-11-08 Name the pins in the MCU after its actual function used
    [mcu.kicad_sch]
2024-11-08 Route USB data signals to STM32
    The CANbus needed to be moved together with ec and ph disable signals.
    Closes #14 and #9
    [HydroponicFlowerControl.kicad_pcb, HydroponicFlowerControl.kicad_sch, mcu.kicad_sch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]
2024-11-08 Connect button to BOOT0
    This is used to enter DFU bootloader
    Closes #26
    [HydroponicFlowerControl.kicad_pcb, mcu.kicad_sch]
2024-11-08 Add standard pinheaders for programming
    Pinout same as STM32 Blue pill
    [HydroponicFlowerControl.kicad_pcb, mcu.kicad_sch]
2024-11-08 Add power out to the digital inputs
    Closes #18
    [HydroponicFlowerControl.kicad_pcb, io.kicad_sch]
2024-11-08 Align pH connector
    See #10
    [HydroponicFlowerControl.kicad_pcb, ph.kicad_sch]
2024-11-08 Align all connectors
    Closes #10
    [HydroponicFlowerControl.kicad_pcb]
2024-11-08 Fix some manufacturing attributes for JLCPCB
    [HydroponicFlowerControl.kicad_pcb, mcu.kicad_sch]
2024-11-08 Update rev to 2
    Closes #27
    [HydroponicFlowerControl.kicad_pcb, HydroponicFlowerControl.kicad_sch, ec.kicad_sch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]
2024-11-12 Fix ERC warnings
    See #28
    [HydroponicFlowerControl.kicad_pcb, HydroponicFlowerControl.kicad_sch, ec.kicad_sch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]
2024-11-12 Add missing rotation offset attribute
    [power.kicad_sch]
2024-11-12 Fix ERC errors
    Closes #28
    [HydroponicFlowerControl.kicad_pcb, HydroponicFlowerControl.kicad_sch, mcu.kicad_sch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]
2024-11-12 Add 1-Wire
    Closes #29
    [HydroponicFlowerControl.kicad_pcb, HydroponicFlowerControl.kicad_sch, io.kicad_sch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]
2024-11-12 Align connector silkscreen
    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
    [HydroponicFlowerControl.kicad_pcb]
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2025-01-14 Connect GND on DC barrel jack
    Closes #35
    [HydroponicFlowerControl.kicad_pcb, power.kicad_sch]
2025-01-14 Cleanup tracks
    Closes #32
    [HydroponicFlowerControl.kicad_pcb]
2025-01-14 Add OSHW logo
    Closes #37
    [HydroponicFlowerControl.kicad_pcb]
2025-01-14 Remove TPS60400 (U11) from pH block
    Closes #30
    [HydroponicFlowerControl.kicad_pcb, ph.kicad_sch]
2025-01-14 Fix silkscreen overlap issues in board
    [HydroponicFlowerControl.kicad_pcb]
2025-01-14 Move Cortex debug to get easier access to TagConnect
    Else it is quite hard to insert or remove the TagConnect
    [HydroponicFlowerControl.kicad_pcb]
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2025-01-14 Update pH connector to combined BNC and SMA footprint
    [HydroponicFlowerControl.kicad_pcb, ph.kicad_sch]
2025-01-14 Remove pH circuits
    And replace with a header to connect to an external HAT board
    Closes #40
    [HydroponicFlowerControl.kicad_pcb, ph.kicad_sch]
2025-01-14 Add dampening on NTC temp signal
    STM32 input is not 5V tolerant so the signal is lowered to 3.3V
    Closes #36
    [HydroponicFlowerControl.kicad_pcb, flow_control.kicad_sch]
2025-01-14 Bump HW rev
    Closes #43
    [HydroponicFlowerControl.kicad_pcb, mcu.kicad_sch]
2025-01-14 Rotate RPi
    Closes #44
    [HydroponicFlowerControl.kicad_pcb]
2025-01-14 Add serial number QR
    Closes #46
    [HydroponicFlowerControl.kicad_pcb]
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2025-01-16 Replace footprint for J18
    Closes #31
    [HydroponicFlowerControl.kicad_pcb, rpi.kicad_sch]
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2025-01-17 Update part for JST 2P connectors
    Closes #41
    [HydroponicFlowerControl.kicad_pcb, ec.kicad_sch, flow_control.kicad_sch]
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2025-11-17 Replace MCU with STM32U575RGT
    Closes #49
    [HydroponicFlowerControl.kicad_pcb, mcu.kicad_sch]
2025-11-17 Increase input voltage range to 10-35V
    See #52
    [HydroponicFlowerControl.kicad_pcb, power.kicad_sch]
2025-11-17 Increase size of inductor L14 to allow more power on the 5V rail
    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
    [HydroponicFlowerControl.kicad_pcb, power.kicad_sch]
2025-11-26 Add Reverse polarity protection
    Closes #55
    [HydroponicFlowerControl.kicad_pcb, HydroponicFlowerControl.kicad_sch, io.kicad_sch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]
2025-12-02 Replace 4 of the 6 highside outputs with TPS4H160B
    See #50
    [HydroponicFlowerControl.kicad_pcb, HydroponicFlowerControl.kicad_sch, flow_control.kicad_sch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]
2025-12-02 Add missing 3d model of DC barrel jack
    [FC681465S-smd.stp]
2025-12-04 Replace the last 2 of the highside outputs with TPS4H160B
    Closes #50
    [HydroponicFlowerControl.kicad_pcb, HydroponicFlowerControl.kicad_sch, flow_control.kicad_sch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]
2025-12-04 Add missing footprint SOP65P780X200-20N
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2025-12-08 Protect CAN connector from over voltage
    Closes #57
    [HydroponicFlowerControl.kicad_pcb, mcu.kicad_sch, power.kicad_sch]
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2026-04-03 Replace diode for Vin from CAN with ideal diode
    See #63
    [HydroponicFlowerControl.kicad_pcb, power.kicad_sch]
2026-04-03 Replace diode for USB power with ideal diode
    Closes #63
    [HydroponicFlowerControl.kicad_pcb, power.kicad_sch]
2026-04-03 Replace 5V stepdown with TPS62933
    Closes #64
    [HydroponicFlowerControl.kicad_pcb, power.kicad_sch]
2026-04-03 Replace TPS26630 with TPS16630
    Without reverse polarity protection (1 Dollar cheaper)
    Closes #62
    [HydroponicFlowerControl.kicad_pcb, power.kicad_sch]
2026-04-04 Upgrade BarrelJAck to a 24V 5A version
    Closes #56
    [HydroponicFlowerControl.kicad_pcb, power.kicad_sch]
2026-04-05 Fix mismatch between inputs to highside switches and outputs
    Closes #60
    [HydroponicFlowerControl.kicad_pcb, flow_control.kicad_sch, mcu.kicad_sch]
2026-04-09 Change pH pinsocket connector from THT to SMD
    Closes #42
    [HydroponicFlowerControl.kicad_pcb, ph.kicad_sch]
